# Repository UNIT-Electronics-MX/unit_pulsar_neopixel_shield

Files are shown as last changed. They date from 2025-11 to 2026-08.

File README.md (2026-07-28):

# Pulsar: Neopixel Shield

The shield matrix is designed to be compatible with the Pulsar development board format, featuring 256 RGB LEDs. This allows for independent control of each pixel to create a wide range of visual effects, from simple patterns (solid colors, bars, gradients) to complex animations (waves, scrolling text, sprites, indicators). This makes it ideal for applications in interactive displays, wearables, and creative projects.

<div align="center">
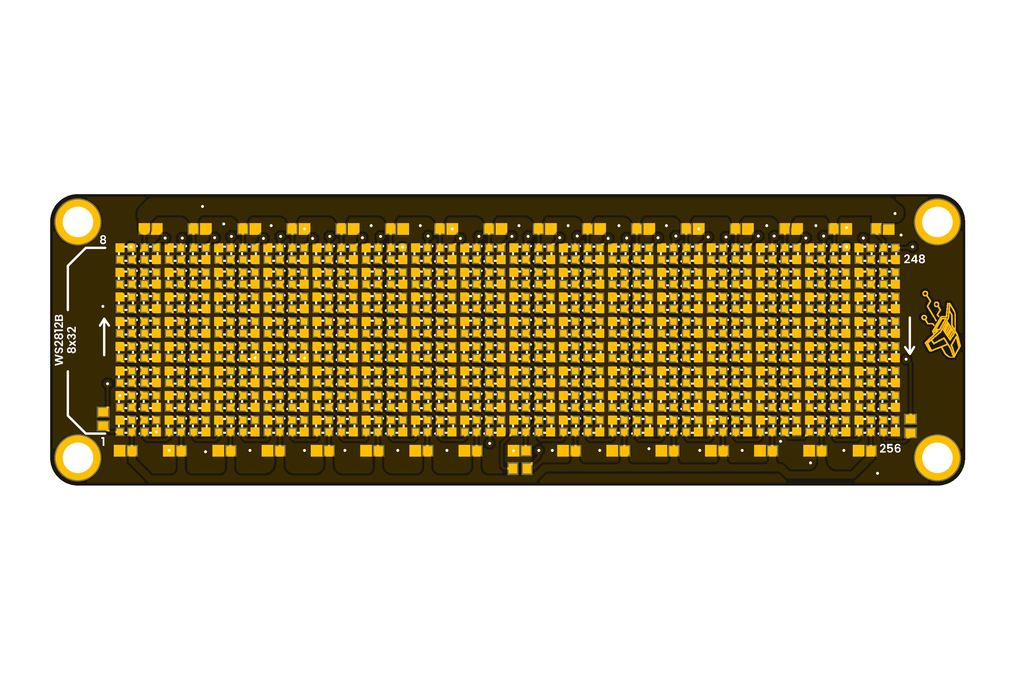
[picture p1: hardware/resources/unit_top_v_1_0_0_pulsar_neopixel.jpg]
Development Board
  
  <p><em>Development Board</em></p>
</div>

<div align="center">

### Quick Setup

[](https://wiki.uelectronics.com/wiki/unit_pulsar_neopixel_shield)
[](./hardware/unit_datasheet_v_1_0_0_ue00118_pulsar_neopixel_shield.pdf)
[](#)
[](#)

</div>

<div align="center" >

## Overview

| Feature | Description |
|---|---|
| **LED Count** | 256 RGB LEDs (WS2812B) |

</div>

## Applications

## Resources

- [Schematic Diagram](./hardware/unit_sch_v_1_0_0_pulsar_neopixel.pdf)
- [Pinout Diagram](./hardware/unit_pinout_v_1_0_0_ue00118_pulsar_neopixel_shield_en.pdf)
- [Getting Started Guide](#)

## 📝 License

All hardware and documentation in this project are licensed under the **MIT License**.  
See [`LICENSE.md`](LICENSE.md) for details.

<div align="center">
  <sub>Template created by UNIT Electronics</sub>
</div>

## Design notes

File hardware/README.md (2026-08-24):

# Hardware

<div align="center">
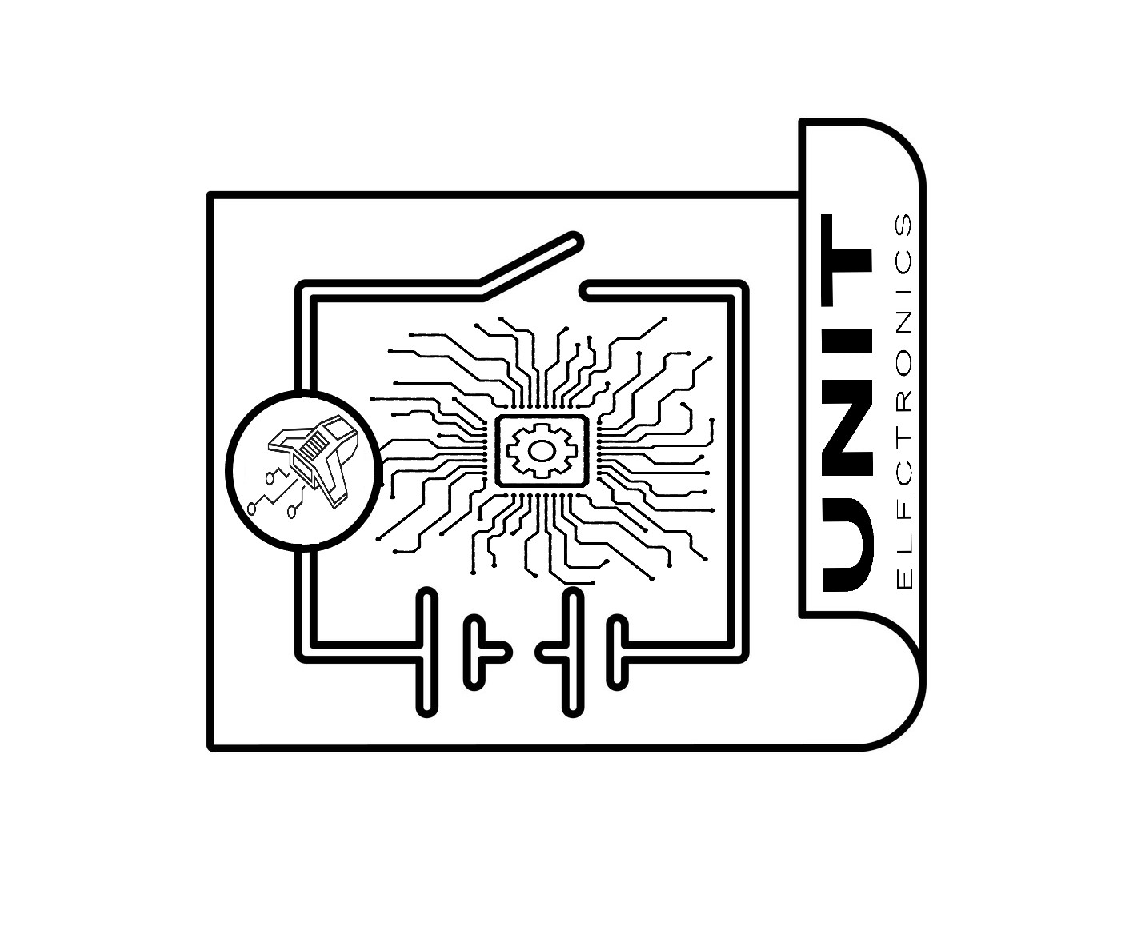
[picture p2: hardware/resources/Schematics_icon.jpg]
<a href="./unit_sch_v_1_0_0_pulsar_neopixel.pdf"><br/>Schematic</a>
</div>

## Pinout

<div align="center">
<a href="./unit_pinout_v_1_0_0_ue00118_pulsar_neopixel_shield_en.pdf">
<br/>
Pinout
</a>
</div>
    
| Pin Label | Function | Notes |
|---|---|---|
| +3V3 | Power Supply | 3.3 V power rail for the shield and external interfaces. |
| GND | Ground | Common ground reference shared by controller boards, LED matrix and expansion connectors. |
| SDA | I²C SDA (A4/D18) | Serial Data Line available through the QWIIC connector. |
| SCL | I²C SCL (A5/D19) | Serial Clock Line available through the QWIIC connector. |
| DI1 | Matrix Data Input 1 | Data input for LED Matrix 1 (LED #1 to LED #128). Available on connector J2. |
| DI2 | Matrix Data Input 2 | Data input for LED Matrix 2 (LED #129 to LED #256). Available on connector J2. |
| DO1 | Matrix Data Output 1 | Data output from Matrix 1 for cascading additional WS2812B devices. Available on connector J1. |
| DO2 | Matrix Data Output 2 | Data output from Matrix 2 for cascading additional WS2812B devices. Available on connector J1. |
| SB1 | Solder Bridge | Optional solder jumper used to electrically connect Matrix 1 and Matrix 2 for single-signal operation (DI1). |

> **SB1 Configuration:**  
> When SB1 is left open, Matrix 1 and Matrix 2 can be controlled independently through DI1 and DI2.  
> When SB1 is shorted, both matrices are electrically linked, allowing all 256 LEDs to operate as a single 8×32 addressable RGB matrix controlled from DI1.

</div>

## Dimensions

<div align="center">
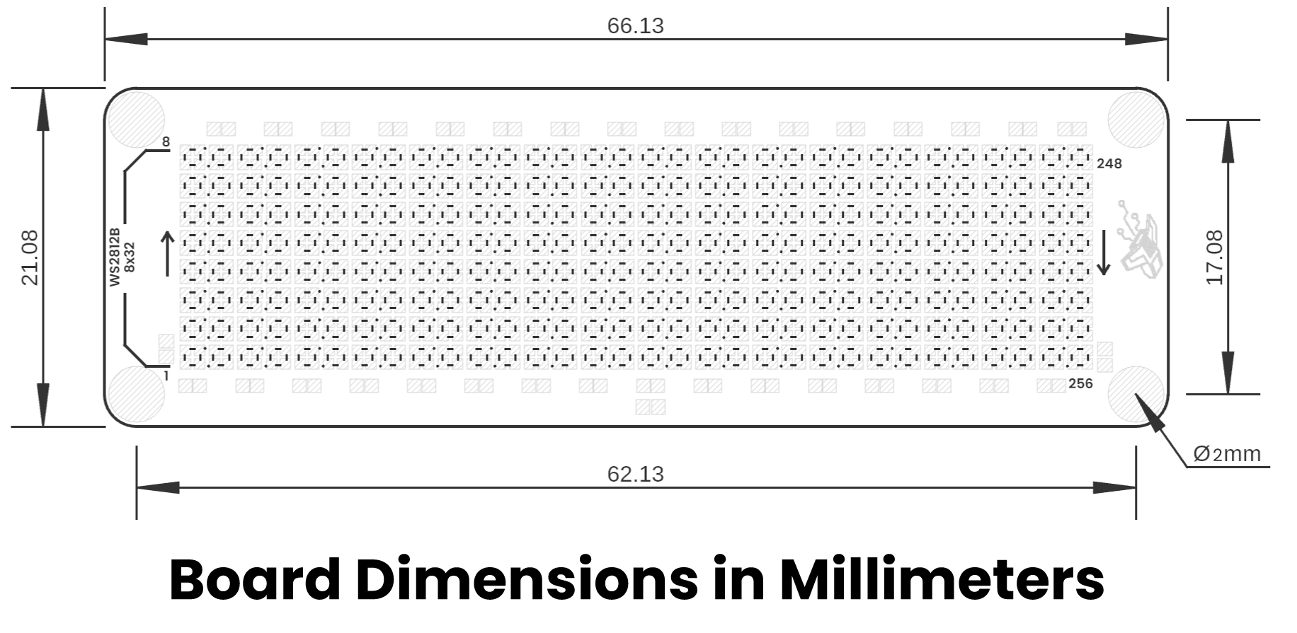
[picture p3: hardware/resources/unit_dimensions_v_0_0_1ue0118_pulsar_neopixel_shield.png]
<a href="./resources/unit_dimensions_v_0_0_1ue0118_pulsar_neopixel_shield.png"><br/> Dimensions</a>
</div>

## Topology

<div align="center">

<div align="center">
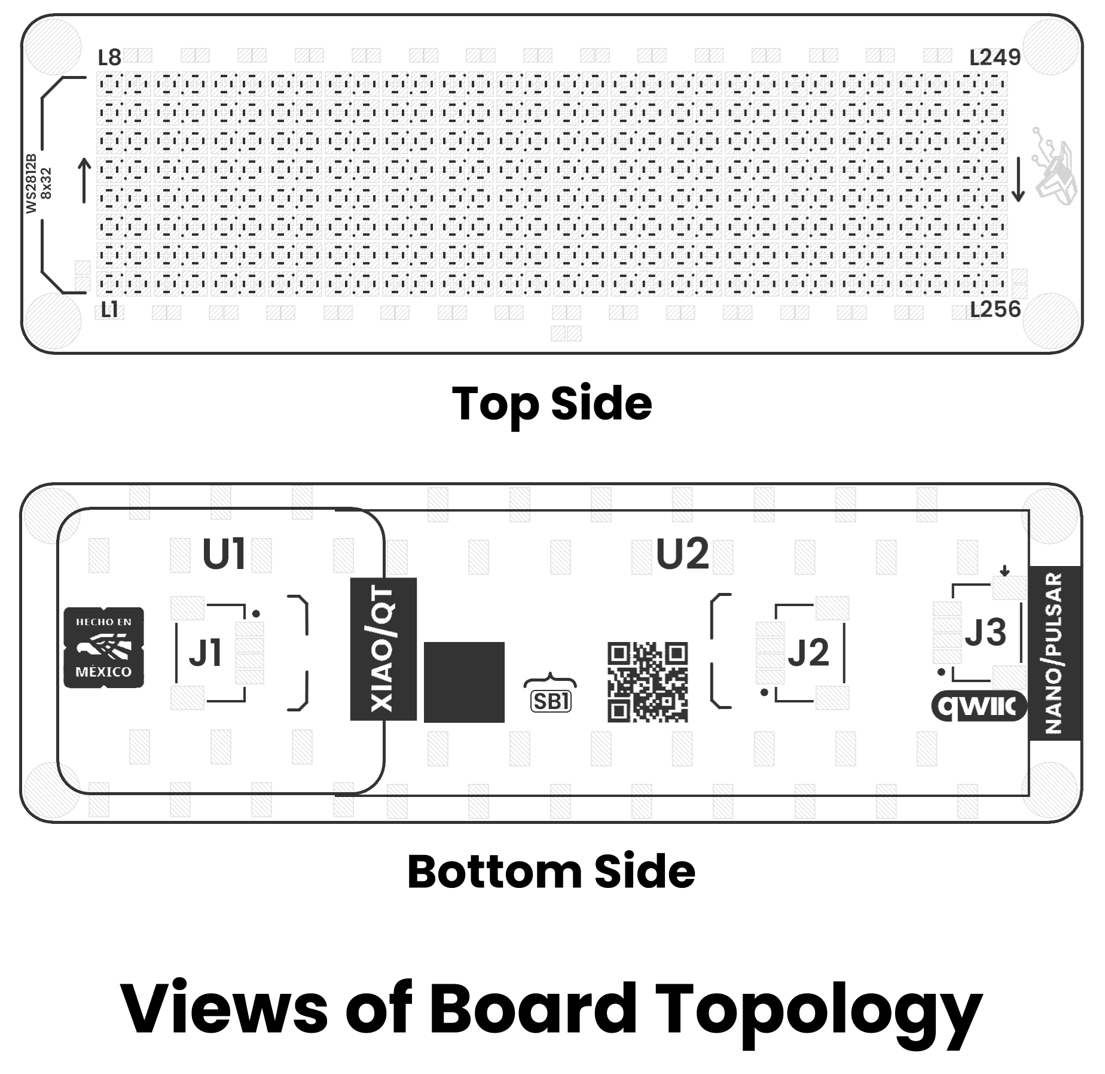
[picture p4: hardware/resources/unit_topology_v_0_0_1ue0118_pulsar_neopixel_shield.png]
<a href="./resources/unit_topology_v_0_0_1ue0118_pulsar_neopixel_shield.png"><br/> Topology</a>
<br/>
<br/>
<br/>

| Ref. | Description |
|---|---|
| L1–L256 | Addressable RGB LEDs, WS2812B-compatible, 1.0 × 1.0 mm package, SMD 1010. |
| U1 | Header connectors for inserting a Pulsar or Nano-format controller board. |
| U2 | Header connectors for inserting a XIAO/QT-format controller board. |
| J1 | WS2812B data output connector, JST 1.0 mm pitch, for external WS2812B expansion from Matrix 1 and Matrix 2. |
| J2 | WS2812B data input connector, JST 1.0 mm pitch, for Matrix 1 and Matrix 2. |
| J3 | QWIIC connector, JST 1.0 mm pitch, for I²C interface. |
| SB1 | Solder bridge/jumper pad used to join both LED matrices so they can be controlled with a single data signal. |

> **SB1 Configuration:**  
> When SB1 is left open, Matrix 1 and Matrix 2 can be controlled independently through DI1 and DI2.  
> When SB1 is shorted, the output of Matrix 1 is routed to the input of Matrix 2, allowing all 256 LEDs to operate as a single 8×32 WS2812B matrix controlled from DI1.

</div>

> **Note:** The module also includes a Qwiic/STEMMA QT connector carrying the same four signals (VCC, GND, SDA, SCL) for effortless daisy-chaining.

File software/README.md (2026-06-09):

# Software

This directory contains the software resources for the RGB LED matrix shield project.

The purpose of this folder is to organize source code, examples, tests, and future software tools related to the control and validation of the shield. The examples included here are intended to help users understand how to interact with the RGB LED matrix using different programming environments.

---

## Directory Structure

```text
software/
├── examples/
│   ├── cpp_examples/
│   └── micropython/
└── README.md
```

---

## Contents

### `examples/`

Contains example projects and test programs for the RGB LED matrix shield.

These examples are organized by programming language or development environment. The current examples are focused on C++/Arduino-based development, while MicroPython examples may be added in the future.

---

## Purpose

This software section is intended to provide:

* Basic test programs.
* Hardware validation examples.
* LED matrix control examples.
* Reference code for future development.
* Starting points for custom animations and interactive applications.

---

## Notes

The examples in this directory are mainly intended for development, debugging, and educational purposes.

Before using any example, make sure to review the pin configuration, LED count, power requirements, and library dependencies.

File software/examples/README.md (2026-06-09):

# Examples

This directory contains example projects for testing and controlling the RGB LED matrix shield.

The examples are organized by programming language or development environment. Each subdirectory contains code focused on a specific implementation or testing approach.

---

## Directory Structure

```text
examples/
├── cpp_examples/
│   ├── neo_esp/
│   ├── neo_esp_offset/
│   ├── neo_esp_test_serial/
│   └── README.md
├── micropython/
└── README.md
```

---

## Available Example Categories

### `cpp_examples/`

Contains C++ examples for controlling the RGB LED matrix using Arduino-compatible development environments.

These examples are useful for:

* Testing individual LEDs.
* Verifying LED indexing.
* Checking matrix orientation.
* Running basic animations.
* Debugging wiring and data signal issues.

---

### `micropython/`

This folder include examples for boards compatible with MicroPython, allowing the matrix shield to be controlled using Python-based scripts.

---

## Recommended Usage

Start with the examples inside `cpp_examples/` if you want to validate the hardware and confirm that the RGB LED matrix is working correctly.

A recommended first test is to use a serial-based example to check:

* Power connection.
* Data pin configuration.
* LED count.
* Matrix direction.
* Individual LED addressing.

---

## Notes

Some examples may require external libraries, such as the Adafruit NeoPixel library.

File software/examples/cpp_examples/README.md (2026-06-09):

# Interactive 8x32 RGB LED Matrix Test

This project provides an interactive serial test program for an 8x32 RGB LED matrix based on WS2812B-compatible addressable LEDs. It uses the `Adafruit_NeoPixel` library to control a total of 257 LEDs: one indicator LED and 256 matrix LEDs.

The main purpose of this code is to verify the correct operation, wiring, indexing, and physical LED arrangement of an 8x32 RGB LED matrix. Through the Serial Monitor, the user can turn on individual LEDs, complete rows, ranges of LEDs, run sequences, and perform visual verification tests.

---

## Features

* Controls an 8x32 RGB LED matrix.
* Supports 256 independently addressable matrix LEDs.
* Uses LED 0 as a status indicator.
* Allows interactive control through the Serial Monitor.
* Provides commands to test individual LEDs, rows, ranges, and full-matrix lighting.
* Includes a verification routine for checking the physical position of LEDs 9 to 16.
* Helps identify LED indexing issues and matrix wiring direction.
* Keeps the indicator LED enabled while testing the matrix.

---

## Hardware Configuration

The system is configured for the following LED layout:

| Element | Description |
| --- | --- |
| Indicator LED | LED 0 |
| Matrix LEDs | LEDs 1 to 256 |
| Matrix size | 8 columns x 32 rows |
| Data pin | Pin 8 |
| LED type | WS2812B-compatible RGB LEDs |
| Color order | GRB |
| Communication speed | 800 kHz |

The matrix is treated as a linear LED strip, where LED 0 is reserved as an indicator and the actual matrix starts at LED 1.

---

## Required Library

This project requires the following Arduino library:

```cpp
#include <Adafruit_NeoPixel.h>
```

You can install it from the Arduino IDE:

1. Open the Arduino IDE.
2. Go to **Sketch > Include Library > Manage Libraries**.
3. Search for **Adafruit NeoPixel**.
4. Install the library by Adafruit.

---

## Main Configuration

```cpp
#define PIN        8
#define NUM_LEDS   257
#define MATRIX_WIDTH  8
#define MATRIX_HEIGHT 32
```

Where:

* `PIN` defines the microcontroller pin connected to the LED matrix data input.
* `NUM_LEDS` is set to `257` because the system uses 1 indicator LED plus 256 matrix LEDs.
* `MATRIX_WIDTH` defines the number of columns in the matrix.
* `MATRIX_HEIGHT` defines the number of rows in the matrix.

---

## LED Indexing

The LED indexing is organized as follows:

* `LED 0`: status indicator.
* `LEDs 1-256`: RGB LED matrix.

The first row of the matrix uses LEDs 1 to 8.

The second row uses LEDs 9 to 16.

The third row uses LEDs 17 to 24.

This pattern continues until LED 256.

| Matrix Row | LED Range |
| --- | --- |
| Row 0 | LEDs 1-8 |
| Row 1 | LEDs 9-16 |
| Row 2 | LEDs 17-24 |
| ... | ... |
| Row 31 | LEDs 249-256 |

---

## Serial Monitor Configuration

To use the program, open the Serial Monitor with the following settings:

```text
Baud rate: 115200
Line ending: Newline
```

After uploading the code, the Serial Monitor will display an interactive menu with the available commands.

---

## Available Commands

| Command | Description | Example |
| --- | --- | --- |
| `L<num>` | Turns on an individual LED | `L1`, `L64`, `L256` |
| `F<num>` | Turns on a full row | `F0`, `F1`, `F31` |
| `C` | Clears all matrix LEDs | `C` |
| `T` | Runs a four-point reference test | `T` |
| `A` | Turns on all matrix LEDs in red | `A` |
| `S` | Runs a sequential LED test from 1 to 256 | `S` |
| `R<start>-<end>` | Turns on a range of LEDs | `R1-8`, `R20-40` |
| `V` | Verifies LEDs 9 to 16 one by one | `V` |
| `M` | Displays the command menu again | `M` |

---

## Command Descriptions

### Individual LED Test

The `L<num>` command turns on a single LED in red.

Example:

```text
L64
```

This turns on physical LED 64.

Valid range:

```text
0 to 256
```

Although LED 0 can be addressed, it is mainly used as the indicator LED.

---

### Row Test

The `F<num>` command turns on an entire matrix row.

Example:

```text
F0
```

This turns on row 0, corresponding to LEDs 1 to 8.

The row uses different colors to identify the beginning and end of the row:

* First LED: red.
* Middle LEDs: blue.
* Last LED: green.

This helps verify the physical orientation of each row.

Valid row range:

```text
0 to 31
```

---

### Clear LEDs

The `C` command turns off all matrix LEDs while keeping LED 0 enabled as a green indicator.

Example:

```text
C
```

---

### Four-Point Reference Test

The `T` command turns on four reference LEDs:

| LED | Color  | Purpose |
| --- | --- | --- |
| LED 1  | Red | Start of row 0 |
| LED 8  | Green  | End of row 0 |
| LED 9  | Blue | Start of row 1 |
| LED 16 | Yellow | End of row 1 |

This test is useful for checking the wiring direction and identifying whether the matrix follows a straight or zigzag arrangement.

Expected reference pattern:

```text
Row 0: LED 1 to LED 8
Row 1: LED 9 to LED 16
```

If the physical position does not match the expected pattern, the matrix may be wired in a zigzag layout or have a different physical LED order.

---

### Turn On All LEDs

The `A` command turns on all 256 matrix LEDs in red.

Example:

```text
A
```

This is useful for checking whether all LEDs are working correctly.

LED 0 remains enabled as a green indicator.

---

### Sequential Test

The `S` command runs a sequence from LED 1 to LED 256.

Example:

```text
S
```

Each LED turns on individually in red for 200 milliseconds.

This test helps verify:

* LED order.
* Missing LEDs.
* Incorrect wiring.
* Physical matrix direction.
* Damaged or disconnected LEDs.

To stop the sequence, send any character through the Serial Monitor.

---

### Range Test

The `R<start>-<end>` command turns on a range of LEDs in red.

Example:

```text
R1-8
```

This turns on LEDs 1 through 8.

Another example:

```text
R129-256
```

This turns on the second half of the matrix.

Valid range:

```text
1 to 256
```

---

### LED Position Verification

The `V` command verifies LEDs 9 to 16 one by one.

Example:

```text
V
```

The program turns on each LED individually and waits for the user to press Enter before continuing.

This test is useful when checking whether the second row of the matrix is physically arranged as expected.

The expected LED order for row 1 may depend on the matrix wiring. In a zigzag layout, the physical direction of every other row may be reversed.

---

## Indicator LED

LED 0 is used as a status indicator.

During setup, LED 0 is turned on with a low-intensity green color:

```cpp
strip.setPixelColor(0, strip.Color(0, 50, 0));
```

This allows the user to verify that the strip is powered and that the program is running.

The indicator LED remains on during most test operations.

---

## Brightness

The brightness is configured with:

```cpp
strip.setBrightness(64);
```

This sets the brightness to a moderate level to reduce current consumption and avoid excessive brightness during testing.

The brightness value can be adjusted from:

```text
0 to 255
```

A higher value increases brightness but also increases current consumption.

---

## Recommended Power Considerations

When turning on all 256 RGB LEDs, especially at high brightness, the matrix may require significant current. For testing purposes, the brightness is limited to 64.

For stable operation:

* Use an external power supply if required.
* Make sure the LED matrix ground and microcontroller ground are connected.
* Avoid powering a large LED matrix directly from a weak USB port.
* Use proper wire thickness for the LED power lines.
* Consider adding a capacitor across the LED power input.

---

## Troubleshooting

### Nothing turns on

Check the following:

* The data pin is connected to pin 8.
* The LED matrix is powered correctly.
* The ground of the microcontroller and the matrix are connected together.
* The correct LED type and color order are selected.
* The Adafruit NeoPixel library is installed.

---

### Colors appear incorrect

The code uses:

```cpp
NEO_GRB + NEO_KHZ800
```

If the colors do not match, the matrix may use a different color order such as RGB instead of GRB.

Try changing:

```cpp
NEO_GRB
```

to:

```cpp
NEO_RGB
```

---

### LED order does not match the expected position

If the LEDs turn on in a different physical order, the matrix may use a zigzag arrangement.

Use the following commands to diagnose the layout:

```text
T
V
S
F0
F1
```

These commands help identify the real physical order of the LEDs.

---

### Some LEDs do not turn on

Possible causes:

* Incorrect soldering.
* Damaged LED.
* Insufficient power.
* Data signal interruption.
* Incorrect LED count.
* Loose connection.

Use the sequential test:

```text
S
```

to identify the first LED where the problem appears.

---

## Code Purpose

This code is mainly intended for hardware validation and debugging of an 8x32 RGB LED matrix. It is especially useful during the development of custom LED shields, display modules, interactive panels, and embedded visual interfaces.

It can be used to verify:

* LED addressing.
* Matrix orientation.
* Data input wiring.
* Row mapping.
* Power stability.
* Individual LED functionality.

---

## Possible Improvements

Future versions of this program could include:

* XY coordinate control.
* Zigzag mapping correction.
* Text scrolling.
* Color selection through serial commands.
* Brightness adjustment through serial commands.
* Animation modes.
* Sprite rendering.
* Matrix graphics library integration.
* Support for multiple data inputs.

---

## Example Workflow

A recommended test sequence is:

```text
C
L1
L8
F0
F1
T
V
R1-16
A
S
```

This sequence allows the user to verify individual LEDs, rows, reference points, LED ranges, full matrix operation, and the complete LED order.

---

## Code

```cpp
#include <Adafruit_NeoPixel.h>

#define PIN        8
#define NUM_LEDS   257  // Total: 1 LED indicador (0) + 256 LEDs de matriz (1-256)
#define MATRIX_WIDTH  8    // 8 columnas
#define MATRIX_HEIGHT 32   // 32 filas

Adafruit_NeoPixel strip(NUM_LEDS, PIN, NEO_GRB + NEO_KHZ800);

void setup() {
  Serial.begin(115200);
  
  strip.begin();
  strip.setBrightness(64);
  strip.clear();
  
  // LED 0 como indicador
  
  strip.setPixelColor(0, strip.Color(0, 50, 0));
  strip.show();
  
  Serial.println("\n\n=== PRUEBA INTERACTIVA LED MATRIZ 8x32 ===");
  Serial.println("LED 0: Indicador (verde tenue)");
  Serial.println("Matriz: LEDs 1-256 (8 columnas x 32 filas)\n");
  
  printMenu();
}

void printMenu() {
  Serial.println("\n--- MENU DE COMANDOS ---");
  Serial.println("L<num>        - Encender LED individual (ej: L1, L64, L256)");
  Serial.println("F<num>        - Encender fila completa (ej: F0, F1, F31)");
  Serial.println("C             - Limpiar todos los LEDs");
  Serial.println("T             - Test 4 esquinas (LEDs 1,8,9,16)");
  Serial.println("A             - Encender TODOS los LEDs en ROJO");
  Serial.println("S             - Secuencia 1-256 uno por uno");
  Serial.println("R<inicio>-<fin> - Rango de LEDs (ej: R1-8)");
  Serial.println("V             - Verificar LEDs 9-16 uno por uno");
  Serial.println("M             - Mostrar este menu");
  Serial.println("\nColores: ROJO por defecto");
  Serial.println("----------------------------------------\n");
}

void encenderLED(int ledNum) {
  if (ledNum < 0 || ledNum > 256) {
    Serial.println("ERROR: LED debe estar entre 0 y 256");
    return;
  }
  
  strip.clear();
  // Mantener LED 0 encendido
  strip.setPixelColor(0, strip.Color(0, 50, 0));
  
  Serial.print("DEBUG: Encendiendo LED fisico ");
  Serial.println(ledNum);
  
  // Encender el LED solicitado en ROJO
  strip.setPixelColor(ledNum, strip.Color(255, 0, 0));
  strip.show();
  
  Serial.print("LED ");
  Serial.print(ledNum);
  Serial.println(" encendido (ROJO)");
}

void encenderFila(int fila) {
  if (fila < 0 || fila >= MATRIX_HEIGHT) {
    Serial.print("ERROR: Fila debe estar entre 0 y ");
    Serial.println(MATRIX_HEIGHT - 1);
    return;
  }
  
  strip.clear();
  // Mantener LED 0 encendido
  strip.setPixelColor(0, strip.Color(0, 50, 0));
  
  // Calcular LEDs de la fila (sin offset porque son LEDs físicos directos)
  int startLED = (fila * MATRIX_WIDTH) + 1; // +1 porque LED 0 es indicador
  
  Serial.print("Fila ");
  Serial.print(fila);
  Serial.print(" - LEDs fisicos: ");
  Serial.print(startLED);
  Serial.print(" a ");
  Serial.println(startLED + MATRIX_WIDTH - 1);
  
  // Encender los 8 LEDs de la fila con colores alternados
  for (int i = 0; i < MATRIX_WIDTH; i++) {
    int ledNum = startLED + i;
    // Alternar colores para identificar cada LED
    if (i == 0) {
      strip.setPixelColor(ledNum, strip.Color(255, 0, 0)); // ROJO - primero
      Serial.print("  LED ");
      Serial.print(ledNum);
      Serial.println(": ROJO (primero)");
    } else if (i == 7) {  // Último LED (columna 7)
      strip.setPixelColor(ledNum, strip.Color(0, 255, 0)); // VERDE - último
      Serial.print("  LED ");
      Serial.print(ledNum);
      Serial.println(": VERDE (ultimo)");
    } else {
      strip.setPixelColor(ledNum, strip.Color(0, 0, 255)); // AZUL - intermedios
    }
  }
  
  strip.show();
}

void limpiarTodo() {
  strip.clear();
  strip.setPixelColor(0, strip.Color(0, 50, 0));
  strip.show();
  Serial.println("Todos los LEDs apagados (excepto indicador)");
}

void encenderTodos() {
  strip.clear();
  strip.setPixelColor(0, strip.Color(0, 50, 0)); // Mantener indicador
  
  // Encender todos los LEDs de la matriz (1-256) en ROJO
  for (int i = 1; i <= 256; i++) {
    strip.setPixelColor(i, strip.Color(255, 0, 0));
  }
  
  strip.show();
  Serial.println("\n=== TODOS LOS LEDs ENCENDIDOS EN ROJO ===");
  Serial.println("LEDs 1-256 encendidos");
  Serial.println("Verifica que todos los LEDs fisicos esten encendidos");
}

void testEsquinas() {
  strip.clear();
  strip.setPixelColor(0, strip.Color(0, 50, 0));
  
  // Fila 0 - primera y última columna
  strip.setPixelColor(1, strip.Color(255, 0, 0));    // LED 1 - ROJO (esquina superior izquierda)
  strip.setPixelColor(8, strip.Color(0, 255, 0));    // LED 8 - VERDE (esquina superior derecha)
  
  // Fila 1 - primera y última columna  
  strip.setPixelColor(9, strip.Color(0, 0, 255));    // LED 9 - AZUL (fila 1, inicio)
  strip.setPixelColor(16, strip.Color(255, 255, 0)); // LED 16 - AMARILLO (fila 1, final)
  
  strip.show();
  
  Serial.println("\n=== TEST 4 PUNTOS CLAVE ===");
  Serial.println("LED 1:  ROJO     (Fila 0, columna 0 - inicio)");
  Serial.println("LED 8:  VERDE    (Fila 0, columna 7 - final)");
  Serial.println("LED 9:  AZUL     (Fila 1, columna 0 - inicio)");
  Serial.println("LED 16: AMARILLO (Fila 1, columna 7 - final)");
  Serial.println("\nPatron zigzag esperado:");
  Serial.println("Fila 0: ROJO -> -> -> VERDE (izq a der, LEDs 1-8)");
  Serial.println("Fila 1: AMARILLO <- <- <- AZUL (der a izq, LEDs 9-16)");
}

void secuencia() {
  Serial.println("\nIniciando secuencia 1-256...");
  Serial.println("Presiona cualquier tecla para detener\n");
  
  for (int i = 1; i <= 256; i++) {
    if (Serial.available() > 0) {
      Serial.read(); // Leer y descartar
      Serial.println("\nSecuencia detenida");
      break;
    }
    
    strip.clear();
    strip.setPixelColor(0, strip.Color(0, 50, 0));
    strip.setPixelColor(i, strip.Color(255, 0, 0));
    strip.show();
    
    Serial.print("LED ");
    Serial.println(i);
    delay(200);
  }
  
  Serial.println("Secuencia completada");
}

void encenderRango(int inicio, int fin) {
  if (inicio < 1 || fin > 256 || inicio > fin) {
    Serial.println("ERROR: Rango invalido (debe ser 1-256)");
    return;
  }
  
  strip.clear();
  strip.setPixelColor(0, strip.Color(0, 50, 0));
  
  for (int i = inicio; i <= fin; i++) {
    strip.setPixelColor(i, strip.Color(255, 0, 0));
  }
  
  strip.show();
  
  Serial.print("LEDs ");
  Serial.print(inicio);
  Serial.print(" a ");
  Serial.print(fin);
  Serial.println(" encendidos (ROJO)");
}

void verificarProblema() {
  Serial.println("\n=== VERIFICACION LEDs 9-16 (Fila 1) ===");
  Serial.println("Encendiendo cada LED individualmente...");
  Serial.println("Observa DONDE se enciende fisicamente cada LED:\n");
  
  for (int i = 9; i <= 16; i++) {
    strip.clear();
    strip.setPixelColor(0, strip.Color(0, 50, 0));
    strip.setPixelColor(i, strip.Color(255, 0, 0));
    strip.show();
    
    Serial.print(">>> LED FISICO ");
    Serial.print(i);
    Serial.println(" ENCENDIDO <<<");
    Serial.println("Anota la posicion fisica en tu matriz (fila/columna)");
    Serial.println("Presiona Enter para continuar...\n");
    
    // Esperar input del usuario
    while (Serial.available() == 0) {
      delay(10);
    }
    // Limpiar buffer
    while (Serial.available() > 0) {
      Serial.read();
    }
  }
  
  Serial.println("\n=== Verificacion completada ===");
  Serial.println("Ahora compara las posiciones fisicas con lo esperado:");
  Serial.println("Fila 1 deberia ser: LEDs 9-16 (en zigzag: 16,15,14,13,12,11,10,9)");
  limpiarTodo();
}

void procesarComando(String comando) {
  comando.trim();
  comando.toUpperCase();
  
  Serial.print("DEBUG: Comando recibido: [");
  Serial.print(comando);
  Serial.print("], Longitud: ");
  Serial.println(comando.length());
  
  if (comando.length() == 0) {
    Serial.println("DEBUG: Comando vacio");
    return;
  }
  
  char cmd = comando.charAt(0);
  
  Serial.print("DEBUG: Primer caracter: [");
  Serial.print(cmd);
  Serial.println("]");
  
  switch(cmd) {
    case 'L': {
      // Encender LED individual: L64
      int ledNum = comando.substring(1).toInt();
      Serial.print("DEBUG: Numero parseado del substring: ");
      Serial.println(ledNum);
      encenderLED(ledNum);
      break;
    }
    
    case 'F': {
      // Encender fila: F0, F1, etc
      int fila = comando.substring(1).toInt();
      encenderFila(fila);
      break;
    }
    
    case 'C': {
      // Limpiar todo
      limpiarTodo();
      break;
    }
    
    case 'T': {
      // Test 4 esquinas
      testEsquinas();
      break;
    }
    
    case 'A': {
      // Encender TODOS los LEDs
      encenderTodos();
      break;
    }
    
    case 'S': {
      // Secuencia completa
      secuencia();
      break;
    }
    
    case 'R': {
      // Rango: R1-16
      int guionPos = comando.indexOf('-');
      if (guionPos > 0) {
        int inicio = comando.substring(1, guionPos).toInt();
        int fin = comando.substring(guionPos + 1).toInt();
        encenderRango(inicio, fin);
      } else {
        Serial.println("ERROR: Formato incorrecto. Usar R<inicio>-<fin>");
      }
      break;
    }
    
    case 'V': {
      // Verificar problema LEDs 9-17
      verificarProblema();
      break;
    }
    
    case 'M': {
      // Mostrar menu
      printMenu();
      break;
    }
    
    default:
      Serial.println("Comando no reconocido. Escribe M para ver el menu");
      break;
  }
}

void loop() {
  if (Serial.available() > 0) {
    String comando = Serial.readStringUntil('\n');
    procesarComando(comando);
  }
}
```

## License

This project can be used, modified, and adapted for educational, prototyping, and hardware testing purposes.

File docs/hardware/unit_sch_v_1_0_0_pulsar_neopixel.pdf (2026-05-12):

WS2812B | WS2812B | WS2812B | WS2812B | WS2812B | WS2812B | WS2812B | WS2812B VCC
VCC | VCC | VCC | VCC | VCC | VCC | VCC
GND | GND | GND | GND | GND | GND | GND | GND
WS2812B | WS2812B | WS2812B | WS2812B | WS2812B | WS2812B | WS2812B | WS2812B VCC
VCC | VCC | VCC | VCC | VCC | VCC | VCC
GND | GND | GND | GND | GND | GND | GND | GND
WS2812B | WS2812B | WS2812B | WS2812B | WS2812B | WS2812B | WS2812B | WS2812B VCC
VCC | VCC | VCC | VCC | VCC | VCC | VCC
GND | GND | GND | GND | GND | GND | GND | GND
WS2812B | WS2812B | WS2812B | WS2812B | WS2812B | WS2812B | WS2812B | WS2812B VCC
VCC | VCC | VCC | VCC | VCC | VCC | VCC
GND | GND | GND | GND | GND | GND | GND | GND
WS2812B | WS2812B | WS2812B | WS2812B | WS2812B | WS2812B | WS2812B | WS2812B VCC
VCC | VCC | VCC | VCC | VCC | VCC | VCC
GND | GND | GND | GND | GND | GND | GND | GND
WS2812B | WS2812B | WS2812B | WS2812B | WS2812B | WS2812B | WS2812B | WS2812B VCC
VCC | VCC | VCC | VCC | VCC | VCC | VCC
GND | GND | GND | GND | GND | GND | GND | GND
WS2812B | WS2812B | WS2812B | WS2812B | WS2812B | WS2812B | WS2812B | WS2812B VCC
VCC | VCC | VCC | VCC | VCC | VCC | VCC
GND | GND | GND | GND | GND | GND | GND | GND
WS2812B | WS2812B | WS2812B | WS2812B | WS2812B | WS2812B | WS2812B | WS2812B VCC
VCC | VCC | VCC | VCC | VCC | VCC | VCC
GND | GND | GND | GND | GND | GND | GND | GND

1uF

### VCC

### GND

1uF

### VCC

### GND

1uF

### VCC

### GND

1uF

### VCC

### GND

1uF

### VCC

### GND

1uF

### VCC

GND | 1uF VCC | GND | 1uF VCC | GND ²⁰⁰ | LED1 DO | P$1 GND | P$3 DI P$4 | VDD P$2
LED2 DO | P$1 GND | P$3 DI P$4 | VDD P$2
LED3 DO | P$1 GND | P$3 DI P$4 | VDD P$2
LED4 DO | P$1 GND | P$3 DI P$4 | VDD P$2
LED5 DO | P$1 GND | P$3 DI P$4 | VDD P$2
LED6 DO | P$1 GND | P$3 DI P$4 | VDD P$2
LED7 DO | P$1 GND | P$3 DI P$4 | VDD P$2
LED8 DO | P$1 GND | P$3 DI P$4 | VDD P$2
LED9 DO | P$1 GND | P$3 DI P$4 | VDD P$2
LED10 DO | P$1 GND | P$3 DI P$4 | VDD P$2
LED11 DO | P$1 GND | P$3 DI P$4 | VDD P$2
LED12 DO | P$1 GND | P$3 DI P$4 | VDD P$2
LED13 DO | P$1 GND | P$3 DI P$4 | VDD P$2
LED14 DO | P$1 GND | P$3 DI P$4 | VDD P$2
LED15 DO | P$1 GND | P$3 DI P$4 | VDD P$2
LED16 DO | P$1 GND | P$3 DI P$4 | VDD P$2
LED17 DO | P$1 GND | P$3 DI P$4 | VDD P$2
LED18 DO | P$1 GND | P$3 DI P$4 | VDD P$2
LED19 DO | P$1 GND | P$3 DI P$4 | VDD P$2
LED20 DO | P$1 GND | P$3 DI P$4 | VDD P$2
LED21 DO | P$1 GND | P$3 DI P$4 | VDD P$2
LED22 DO | P$1 GND | P$3 DI P$4 | VDD P$2
LED23 DO | P$1 GND | P$3 DI P$4 | VDD P$2
LED24 DO | P$1 GND | P$3 DI P$4 | VDD P$2
LED25 DO | P$1 GND | P$3 DI P$4 | VDD P$2
LED26 DO | P$1 GND | P$3 DI P$4 | VDD P$2
LED27 DO | P$1 GND | P$3 DI P$4 | VDD P$2
LED28 DO | P$1 GND | P$3 DI P$4 | VDD P$2
LED29 DO | P$1 GND | P$3 DI P$4 | VDD P$2
LED30 DO | P$1 GND | P$3 DI P$4 | VDD P$2
LED31 DO | P$1 GND | P$3 DI P$4 | VDD P$2
LED32 DO | P$1 GND | P$3 DI P$4 | VDD P$2
LED33 DO | P$1 GND | P$3 DI P$4 | VDD P$2
LED34 DO | P$1 GND | P$3 DI P$4 | VDD P$2
LED35 DO | P$1 GND | P$3 DI P$4 | VDD P$2
LED36 DO | P$1 GND | P$3 DI P$4 | VDD P$2
LED37 DO | P$1 GND | P$3 DI P$4 | VDD P$2
LED38 DO | P$1 GND | P$3 DI P$4 | VDD P$2
LED39 DO | P$1 GND | P$3 DI P$4 | VDD P$2
LED40 DO | P$1 GND | P$3 DI P$4 | VDD P$2
LED41 DO | P$1 GND | P$3 DI P$4 | VDD P$2
LED42 DO | P$1 GND | P$3 DI P$4 | VDD P$2
LED43 DO | P$1 GND | P$3 DI P$4 | VDD P$2
LED44 DO | P$1 GND | P$3 DI P$4 | VDD P$2
LED45 DO | P$1 GND | P$3 DI P$4 | VDD P$2
LED46 DO | P$1 GND | P$3 DI P$4 | VDD P$2
LED47 DO | P$1 GND | P$3 DI P$4 | VDD P$2
LED48 DO | P$1 GND | P$3 DI P$4 | VDD P$2
LED49 DO | P$1 GND | P$3 DI P$4 | VDD P$2
LED50 DO | P$1 GND | P$3 DI P$4 | VDD P$2
LED51 DO | P$1 GND | P$3 DI P$4 | VDD P$2
LED52 DO | P$1 GND | P$3 DI P$4 | VDD P$2
LED53 DO | P$1 GND | P$3 DI P$4 | VDD P$2
LED54 DO | P$1 GND | P$3 DI P$4 | VDD P$2
LED55 DO | P$1 GND | P$3 DI P$4 | VDD P$2
LED56 DO | P$1 GND | P$3 DI P$4 | VDD P$2
LED57 DO | P$1 GND | P$3 DI P$4 | VDD P$2
LED58 DO | P$1 GND | P$3 DI P$4 | VDD P$2
LED59 DO | P$1 GND | P$3 DI P$4 | VDD P$2
LED60 DO | P$1 GND | P$3 DI P$4 | VDD P$2
LED61 DO | P$1 GND | P$3 DI P$4 | VDD P$2
LED62 DO | P$1 GND | P$3 DI P$4 | VDD P$2
LED63 DO | P$1 GND | P$3 DI P$4 | VDD P$2
LED64 DO | P$1 GND | P$3 DI P$4 | VDD P$2

C9

C10

C11

C12

C13

C14 | C¹⁵ | C¹⁶ R¹ DI1/5.2B | DO¹/2.1A
UE0112 | 1 Matrix 1

A

B | B
C | C
D | D

E

1 | 2 | 3 | 4 | 5 | 6 | 7 | 8

A

E

07/10/2025 05:48 p. m. | 1 | 5 Title: UE0118-Neopixel Shield v9
SKU: Last date time: | REV: SHEET: | of File: | Sheet description: | Author: Alberto Villanueva THE INFORMATION CONTAINED IN THIS DRAWING IS THE SOLE PROPERTY OF UNIT ELECTRONICS. ANY REPRODUCTION IN PART OR WHOLE IS

STRICTLY PROHIBITED WITHOUT WRITTEN PERMISSION. PROPRIETARY

WS2812B | WS2812B | WS2812B | WS2812B | WS2812B | WS2812B | WS2812B | WS2812B VCC
VCC | VCC | VCC | VCC | VCC | VCC | VCC
WS2812B | WS2812B | WS2812B | WS2812B | WS2812B | WS2812B | WS2812B | WS2812B VCC
VCC | VCC | VCC | VCC | VCC | VCC | VCC
GND | GND | GND | GND | GND | GND | GND | GND
WS2812B | WS2812B | WS2812B | WS2812B | WS2812B | WS2812B | WS2812B | WS2812B VCC
VCC | VCC | VCC | VCC | VCC | VCC | VCC
GND | GND | GND | GND | GND | GND | GND | GND
WS2812B | WS2812B | WS2812B | WS2812B | WS2812B | WS2812B | WS2812B | WS2812B VCC
VCC | VCC | VCC | VCC | VCC | VCC | VCC
GND | GND | GND | GND | GND | GND | GND | GND
WS2812B | WS2812B | WS2812B | WS2812B | WS2812B | WS2812B | WS2812B | WS2812B VCC
VCC | VCC | VCC | VCC | VCC | VCC | VCC
GND | GND | GND | GND | GND | GND | GND | GND
WS2812B | WS2812B | WS2812B | WS2812B | WS2812B | WS2812B | WS2812B | WS2812B VCC
VCC | VCC | VCC | VCC | VCC | VCC | VCC
GND | GND | GND | GND | GND | GND | GND | GND
WS2812B | WS2812B | WS2812B | WS2812B | WS2812B | WS2812B | WS2812B | WS2812B VCC
VCC | VCC | VCC | VCC | VCC | VCC | VCC
GND | GND | GND | GND | GND | GND | GND | GND
WS2812B | WS2812B | WS2812B | WS2812B | WS2812B | WS2812B | WS2812B | WS2812B VCC
VCC | VCC | VCC | VCC | VCC | VCC | VCC
GND | GND | GND | GND | GND | GND | GND | GND

1uF

### VCC

### GND

1uF

### VCC

### GND

1uF

### VCC

### GND

1uF

### VCC

### GND

1uF

### VCC

### GND

1uF

### VCC

GND | 1uF VCC | GND | 1uF VCC | GND
LED65 DO | P$1 GND | P$3 DI P$4 | VDD P$2
LED66 DO | P$1 GND | P$3 DI P$4 | VDD P$2
LED67 DO | P$1 GND | P$3 DI P$4 | VDD P$2
LED68 DO | P$1 GND | P$3 DI P$4 | VDD P$2
LED69 DO | P$1 GND | P$3 DI P$4 | VDD P$2
LED70 DO | P$1 GND | P$3 DI P$4 | VDD P$2
LED71 DO | P$1 GND | P$3 DI P$4 | VDD P$2
LED72 DO | P$1 GND | P$3 DI P$4 | VDD P$2
LED73 DO | P$1 GND | P$3 DI P$4 | VDD P$2
LED74 DO | P$1 GND | P$3 DI P$4 | VDD P$2
LED75 DO | P$1 GND | P$3 DI P$4 | VDD P$2
LED76 DO | P$1 GND | P$3 DI P$4 | VDD P$2
LED77 DO | P$1 GND | P$3 DI P$4 | VDD P$2
LED78 DO | P$1 GND | P$3 DI P$4 | VDD P$2
LED79 DO | P$1 GND | P$3 DI P$4 | VDD P$2
LED80 DO | P$1 GND | P$3 DI P$4 | VDD P$2
LED81 DO | P$1 GND | P$3 DI P$4 | VDD P$2
LED82 DO | P$1 GND | P$3 DI P$4 | VDD P$2
LED83 DO | P$1 GND | P$3 DI P$4 | VDD P$2
LED84 DO | P$1 GND | P$3 DI P$4 | VDD P$2
LED85 DO | P$1 GND | P$3 DI P$4 | VDD P$2
LED86 DO | P$1 GND | P$3 DI P$4 | VDD P$2
LED87 DO | P$1 GND | P$3 DI P$4 | VDD P$2
LED88 DO | P$1 GND | P$3 DI P$4 | VDD P$2
LED89 DO | P$1 GND | P$3 DI P$4 | VDD P$2
LED90 DO | P$1 GND | P$3 DI P$4 | VDD P$2
LED91 DO | P$1 GND | P$3 DI P$4 | VDD P$2
LED92 DO | P$1 GND | P$3 DI P$4 | VDD P$2
LED93 DO | P$1 GND | P$3 DI P$4 | VDD P$2
LED94 DO | P$1 GND | P$3 DI P$4 | VDD P$2
LED95 DO | P$1 GND | P$3 DI P$4 | VDD P$2
LED96 DO | P$1 GND | P$3 DI P$4 | VDD P$2
LED97 DO | P$1 GND | P$3 DI P$4 | VDD P$2
LED98 DO | P$1 GND | P$3 DI P$4 | VDD P$2
LED99 DO | P$1 GND | P$3 DI P$4 | VDD P$2
LED100 DO | P$1 GND | P$3 DI P$4 | VDD P$2
LED101 DO | P$1 GND | P$3 DI P$4 | VDD P$2
LED102 DO | P$1 GND | P$3 DI P$4 | VDD P$2
LED103 DO | P$1 GND | P$3 DI P$4 | VDD P$2
LED104 DO | P$1 GND | P$3 DI P$4 | VDD P$2
LED105 DO | P$1 GND | P$3 DI P$4 | VDD P$2
LED106 DO | P$1 GND | P$3 DI P$4 | VDD P$2
LED107 DO | P$1 GND | P$3 DI P$4 | VDD P$2
LED108 DO | P$1 GND | P$3 DI P$4 | VDD P$2
LED109 DO | P$1 GND | P$3 DI P$4 | VDD P$2
LED110 DO | P$1 GND | P$3 DI P$4 | VDD P$2
LED111 DO | P$1 GND | P$3 DI P$4 | VDD P$2
LED112 DO | P$1 GND | P$3 DI P$4 | VDD P$2
LED113 DO | P$1 GND | P$3 DI P$4 | VDD P$2
LED114 DO | P$1 GND | P$3 DI P$4 | VDD P$2
LED115 DO | P$1 GND | P$3 DI P$4 | VDD P$2
LED116 DO | P$1 GND | P$3 DI P$4 | VDD P$2
LED117 DO | P$1 GND | P$3 DI P$4 | VDD P$2
LED118 DO | P$1 GND | P$3 DI P$4 | VDD P$2
LED119 DO | P$1 GND | P$3 DI P$4 | VDD P$2
LED120 DO | P$1 GND | P$3 DI P$4 | VDD P$2
LED121 DO | P$1 GND | P$3 DI P$4 | VDD P$2
LED122 DO | P$1 GND | P$3 DI P$4 | VDD P$2
LED123 DO | P$1 GND | P$3 DI P$4 | VDD P$2
LED124 DO | P$1 GND | P$3 DI P$4 | VDD P$2
LED125 DO | P$1 GND | P$3 DI P$4 | VDD P$2
LED126 DO | P$1 GND | P$3 DI P$4 | VDD P$2
LED127 DO | P$1 GND | P$3 DI P$4 | VDD P$2
LED128 DO | P$1 GND | P$3 DI P$4 | VDD P$2

C1

C2

C3

C4

C5

C6 | C⁷ | C⁸ DO¹/1.8E | DO²/5.3B
UE0112 | 1 Matrix 2

A

B | B
C | C
D | D

E

A

E

07/10/2025 05:48 p. m. | 2 | 5 Title: UE0118-Neopixel Shield v9
SKU: Last date time: | REV: SHEET: | of File: | Sheet description: | Author: Alberto Villanueva THE INFORMATION CONTAINED IN THIS DRAWING IS THE SOLE PROPERTY OF UNIT ELECTRONICS. ANY REPRODUCTION IN PART OR WHOLE IS

WS2812B | WS2812B | WS2812B | WS2812B | WS2812B | WS2812B | WS2812B | WS2812B VCC
VCC | VCC | VCC | VCC | VCC | VCC | VCC
WS2812B | WS2812B | WS2812B | WS2812B | WS2812B | WS2812B | WS2812B | WS2812B VCC
VCC | VCC | VCC | VCC | VCC | VCC | VCC
GND | GND | GND | GND | GND | GND | GND | GND
WS2812B | WS2812B | WS2812B | WS2812B | WS2812B | WS2812B | WS2812B | WS2812B VCC
VCC | VCC | VCC | VCC | VCC | VCC | VCC
GND | GND | GND | GND | GND | GND | GND | GND
WS2812B | WS2812B | WS2812B | WS2812B | WS2812B | WS2812B | WS2812B | WS2812B VCC
VCC | VCC | VCC | VCC | VCC | VCC | VCC
GND | GND | GND | GND | GND | GND | GND | GND
WS2812B | WS2812B | WS2812B | WS2812B | WS2812B | WS2812B | WS2812B | WS2812B VCC
VCC | VCC | VCC | VCC | VCC | VCC | VCC
GND | GND | GND | GND | GND | GND | GND | GND
WS2812B | WS2812B | WS2812B | WS2812B | WS2812B | WS2812B | WS2812B | WS2812B VCC
VCC | VCC | VCC | VCC | VCC | VCC | VCC
GND | GND | GND | GND | GND | GND | GND | GND
WS2812B | WS2812B | WS2812B | WS2812B | WS2812B | WS2812B | WS2812B | WS2812B VCC
VCC | VCC | VCC | VCC | VCC | VCC | VCC
GND | GND | GND | GND | GND | GND | GND | GND
WS2812B | WS2812B | WS2812B | WS2812B | WS2812B | WS2812B | WS2812B | WS2812B VCC
VCC | VCC | VCC | VCC | VCC | VCC | VCC
GND | GND | GND | GND | GND | GND | GND | GND

1uF

### VCC

### GND

1uF

### VCC

### GND

1uF

### VCC

### GND

1uF

### VCC

### GND

1uF

### VCC

### GND

1uF

### VCC

GND | 1uF VCC | GND | 1uF VCC | GND ²⁰⁰ | LED129 DO | P$1 GND | P$3 DI P$4 | VDD P$2
LED130 DO | P$1 GND | P$3 DI P$4 | VDD P$2
LED131 DO | P$1 GND | P$3 DI P$4 | VDD P$2
LED132 DO | P$1 GND | P$3 DI P$4 | VDD P$2
LED133 DO | P$1 GND | P$3 DI P$4 | VDD P$2
LED134 DO | P$1 GND | P$3 DI P$4 | VDD P$2
LED135 DO | P$1 GND | P$3 DI P$4 | VDD P$2
LED136 DO | P$1 GND | P$3 DI P$4 | VDD P$2
LED137 DO | P$1 GND | P$3 DI P$4 | VDD P$2
LED138 DO | P$1 GND | P$3 DI P$4 | VDD P$2
LED139 DO | P$1 GND | P$3 DI P$4 | VDD P$2
LED140 DO | P$1 GND | P$3 DI P$4 | VDD P$2
LED141 DO | P$1 GND | P$3 DI P$4 | VDD P$2
LED142 DO | P$1 GND | P$3 DI P$4 | VDD P$2
LED143 DO | P$1 GND | P$3 DI P$4 | VDD P$2
LED144 DO | P$1 GND | P$3 DI P$4 | VDD P$2
LED145 DO | P$1 GND | P$3 DI P$4 | VDD P$2
LED146 DO | P$1 GND | P$3 DI P$4 | VDD P$2
LED147 DO | P$1 GND | P$3 DI P$4 | VDD P$2
LED148 DO | P$1 GND | P$3 DI P$4 | VDD P$2
LED149 DO | P$1 GND | P$3 DI P$4 | VDD P$2
LED150 DO | P$1 GND | P$3 DI P$4 | VDD P$2
LED151 DO | P$1 GND | P$3 DI P$4 | VDD P$2
LED152 DO | P$1 GND | P$3 DI P$4 | VDD P$2
LED153 DO | P$1 GND | P$3 DI P$4 | VDD P$2
LED154 DO | P$1 GND | P$3 DI P$4 | VDD P$2
LED155 DO | P$1 GND | P$3 DI P$4 | VDD P$2
LED156 DO | P$1 GND | P$3 DI P$4 | VDD P$2
LED157 DO | P$1 GND | P$3 DI P$4 | VDD P$2
LED158 DO | P$1 GND | P$3 DI P$4 | VDD P$2
LED159 DO | P$1 GND | P$3 DI P$4 | VDD P$2
LED160 DO | P$1 GND | P$3 DI P$4 | VDD P$2
LED161 DO | P$1 GND | P$3 DI P$4 | VDD P$2
LED162 DO | P$1 GND | P$3 DI P$4 | VDD P$2
LED163 DO | P$1 GND | P$3 DI P$4 | VDD P$2
LED164 DO | P$1 GND | P$3 DI P$4 | VDD P$2
LED165 DO | P$1 GND | P$3 DI P$4 | VDD P$2
LED166 DO | P$1 GND | P$3 DI P$4 | VDD P$2
LED167 DO | P$1 GND | P$3 DI P$4 | VDD P$2
LED168 DO | P$1 GND | P$3 DI P$4 | VDD P$2
LED169 DO | P$1 GND | P$3 DI P$4 | VDD P$2
LED170 DO | P$1 GND | P$3 DI P$4 | VDD P$2
LED171 DO | P$1 GND | P$3 DI P$4 | VDD P$2
LED172 DO | P$1 GND | P$3 DI P$4 | VDD P$2
LED173 DO | P$1 GND | P$3 DI P$4 | VDD P$2
LED174 DO | P$1 GND | P$3 DI P$4 | VDD P$2
LED175 DO | P$1 GND | P$3 DI P$4 | VDD P$2
LED176 DO | P$1 GND | P$3 DI P$4 | VDD P$2
LED177 DO | P$1 GND | P$3 DI P$4 | VDD P$2
LED178 DO | P$1 GND | P$3 DI P$4 | VDD P$2
LED179 DO | P$1 GND | P$3 DI P$4 | VDD P$2
LED180 DO | P$1 GND | P$3 DI P$4 | VDD P$2
LED181 DO | P$1 GND | P$3 DI P$4 | VDD P$2
LED182 DO | P$1 GND | P$3 DI P$4 | VDD P$2
LED183 DO | P$1 GND | P$3 DI P$4 | VDD P$2
LED184 DO | P$1 GND | P$3 DI P$4 | VDD P$2
LED185 DO | P$1 GND | P$3 DI P$4 | VDD P$2
LED186 DO | P$1 GND | P$3 DI P$4 | VDD P$2
LED187 DO | P$1 GND | P$3 DI P$4 | VDD P$2
LED188 DO | P$1 GND | P$3 DI P$4 | VDD P$2
LED189 DO | P$1 GND | P$3 DI P$4 | VDD P$2
LED190 DO | P$1 GND | P$3 DI P$4 | VDD P$2
LED191 DO | P$1 GND | P$3 DI P$4 | VDD P$2
LED192 DO | P$1 GND | P$3 DI P$4 | VDD P$2

C17

C18

C19

C20

C21

C22 | C²³ | C²⁴ R⁴ DI2/5.2B | DO³/4.1A
UE0112 | 1 Matrix 2

A

B | B
C | C
D | D

E

A

E

07/10/2025 05:48 p. m. | 3 | 5 Title: UE0118-Neopixel Shield v9
SKU: Last date time: | REV: SHEET: | of File: | Sheet description: | Author: Alberto Villanueva THE INFORMATION CONTAINED IN THIS DRAWING IS THE SOLE PROPERTY OF UNIT ELECTRONICS. ANY REPRODUCTION IN PART OR WHOLE IS

WS2812B | WS2812B | WS2812B | WS2812B | WS2812B | WS2812B | WS2812B | WS2812B VCC
VCC | VCC | VCC | VCC | VCC | VCC | VCC
WS2812B | WS2812B | WS2812B | WS2812B | WS2812B | WS2812B | WS2812B | WS2812B VCC
VCC | VCC | VCC | VCC | VCC | VCC | VCC
GND | GND | GND | GND | GND | GND | GND | GND
WS2812B | WS2812B | WS2812B | WS2812B | WS2812B | WS2812B | WS2812B | WS2812B VCC
VCC | VCC | VCC | VCC | VCC | VCC | VCC
GND | GND | GND | GND | GND | GND | GND | GND
WS2812B | WS2812B | WS2812B | WS2812B | WS2812B | WS2812B | WS2812B | WS2812B VCC
VCC | VCC | VCC | VCC | VCC | VCC | VCC
GND | GND | GND | GND | GND | GND | GND | GND
WS2812B | WS2812B | WS2812B | WS2812B | WS2812B | WS2812B | WS2812B | WS2812B VCC
VCC | VCC | VCC | VCC | VCC | VCC | VCC
GND | GND | GND | GND | GND | GND | GND | GND
WS2812B | WS2812B | WS2812B | WS2812B | WS2812B | WS2812B | WS2812B | WS2812B VCC
VCC | VCC | VCC | VCC | VCC | VCC | VCC
GND | GND | GND | GND | GND | GND | GND | GND
WS2812B | WS2812B | WS2812B | WS2812B | WS2812B | WS2812B | WS2812B | WS2812B VCC
VCC | VCC | VCC | VCC | VCC | VCC | VCC
GND | GND | GND | GND | GND | GND | GND | GND
WS2812B | WS2812B | WS2812B | WS2812B | WS2812B | WS2812B | WS2812B | WS2812B VCC
VCC | VCC | VCC | VCC | VCC | VCC | VCC
GND | GND | GND | GND | GND | GND | GND | GND

1uF

### VCC

### GND

1uF

### VCC

### GND

1uF

### VCC

### GND

1uF

### VCC

### GND

1uF

### VCC

### GND

1uF

### VCC

GND | 1uF VCC | GND | 1uF VCC | GND | 200
LED193 DO | P$1 GND | P$3 DI P$4 | VDD P$2
LED194 DO | P$1 GND | P$3 DI P$4 | VDD P$2
LED195 DO | P$1 GND | P$3 DI P$4 | VDD P$2
LED196 DO | P$1 GND | P$3 DI P$4 | VDD P$2
LED197 DO | P$1 GND | P$3 DI P$4 | VDD P$2
LED198 DO | P$1 GND | P$3 DI P$4 | VDD P$2
LED199 DO | P$1 GND | P$3 DI P$4 | VDD P$2
LED200 DO | P$1 GND | P$3 DI P$4 | VDD P$2
LED201 DO | P$1 GND | P$3 DI P$4 | VDD P$2
LED202 DO | P$1 GND | P$3 DI P$4 | VDD P$2
LED203 DO | P$1 GND | P$3 DI P$4 | VDD P$2
LED204 DO | P$1 GND | P$3 DI P$4 | VDD P$2
LED205 DO | P$1 GND | P$3 DI P$4 | VDD P$2
LED206 DO | P$1 GND | P$3 DI P$4 | VDD P$2
LED207 DO | P$1 GND | P$3 DI P$4 | VDD P$2
LED208 DO | P$1 GND | P$3 DI P$4 | VDD P$2
LED209 DO | P$1 GND | P$3 DI P$4 | VDD P$2
LED210 DO | P$1 GND | P$3 DI P$4 | VDD P$2
LED211 DO | P$1 GND | P$3 DI P$4 | VDD P$2
LED212 DO | P$1 GND | P$3 DI P$4 | VDD P$2
LED213 DO | P$1 GND | P$3 DI P$4 | VDD P$2
LED214 DO | P$1 GND | P$3 DI P$4 | VDD P$2
LED215 DO | P$1 GND | P$3 DI P$4 | VDD P$2
LED216 DO | P$1 GND | P$3 DI P$4 | VDD P$2
LED217 DO | P$1 GND | P$3 DI P$4 | VDD P$2
LED218 DO | P$1 GND | P$3 DI P$4 | VDD P$2
LED219 DO | P$1 GND | P$3 DI P$4 | VDD P$2
LED220 DO | P$1 GND | P$3 DI P$4 | VDD P$2
LED221 DO | P$1 GND | P$3 DI P$4 | VDD P$2
LED222 DO | P$1 GND | P$3 DI P$4 | VDD P$2
LED223 DO | P$1 GND | P$3 DI P$4 | VDD P$2
LED224 DO | P$1 GND | P$3 DI P$4 | VDD P$2
LED225 DO | P$1 GND | P$3 DI P$4 | VDD P$2
LED226 DO | P$1 GND | P$3 DI P$4 | VDD P$2
LED227 DO | P$1 GND | P$3 DI P$4 | VDD P$2
LED228 DO | P$1 GND | P$3 DI P$4 | VDD P$2
LED229 DO | P$1 GND | P$3 DI P$4 | VDD P$2
LED230 DO | P$1 GND | P$3 DI P$4 | VDD P$2
LED231 DO | P$1 GND | P$3 DI P$4 | VDD P$2
LED232 DO | P$1 GND | P$3 DI P$4 | VDD P$2
LED233 DO | P$1 GND | P$3 DI P$4 | VDD P$2
LED234 DO | P$1 GND | P$3 DI P$4 | VDD P$2
LED235 DO | P$1 GND | P$3 DI P$4 | VDD P$2
LED236 DO | P$1 GND | P$3 DI P$4 | VDD P$2
LED237 DO | P$1 GND | P$3 DI P$4 | VDD P$2
LED238 DO | P$1 GND | P$3 DI P$4 | VDD P$2
LED239 DO | P$1 GND | P$3 DI P$4 | VDD P$2
LED240 DO | P$1 GND | P$3 DI P$4 | VDD P$2
LED241 DO | P$1 GND | P$3 DI P$4 | VDD P$2
LED242 DO | P$1 GND | P$3 DI P$4 | VDD P$2
LED243 DO | P$1 GND | P$3 DI P$4 | VDD P$2
LED244 DO | P$1 GND | P$3 DI P$4 | VDD P$2
LED245 DO | P$1 GND | P$3 DI P$4 | VDD P$2
LED246 DO | P$1 GND | P$3 DI P$4 | VDD P$2
LED247 DO | P$1 GND | P$3 DI P$4 | VDD P$2
LED248 DO | P$1 GND | P$3 DI P$4 | VDD P$2
LED249 DO | P$1 GND | P$3 DI P$4 | VDD P$2
LED250 DO | P$1 GND | P$3 DI P$4 | VDD P$2
LED251 DO | P$1 GND | P$3 DI P$4 | VDD P$2
LED252 DO | P$1 GND | P$3 DI P$4 | VDD P$2
LED253 DO | P$1 GND | P$3 DI P$4 | VDD P$2
LED254 DO | P$1 GND | P$3 DI P$4 | VDD P$2
LED255 DO | P$1 GND | P$3 DI P$4 | VDD P$2
LED256 DO | P$1 GND | P$3 DI P$4 | VDD P$2

C25

C26

C27

C28

C29

C30 | C³¹ | C³² | R⁷ DO³/3.8E | DO⁴/5.3B
UE0112 | 1 Matrix 2

A

B | B
C | C
D | D

E

A

E

07/10/2025 05:48 p. m. | 4 | 5 Title: UE0118-Neopixel Shield v9
SKU: Last date time: | REV: SHEET: | of File: | Sheet description: | Author: Alberto Villanueva THE INFORMATION CONTAINED IN THIS DRAWING IS THE SOLE PROPERTY OF UNIT ELECTRONICS. ANY REPRODUCTION IN PART OR WHOLE IS

A

A

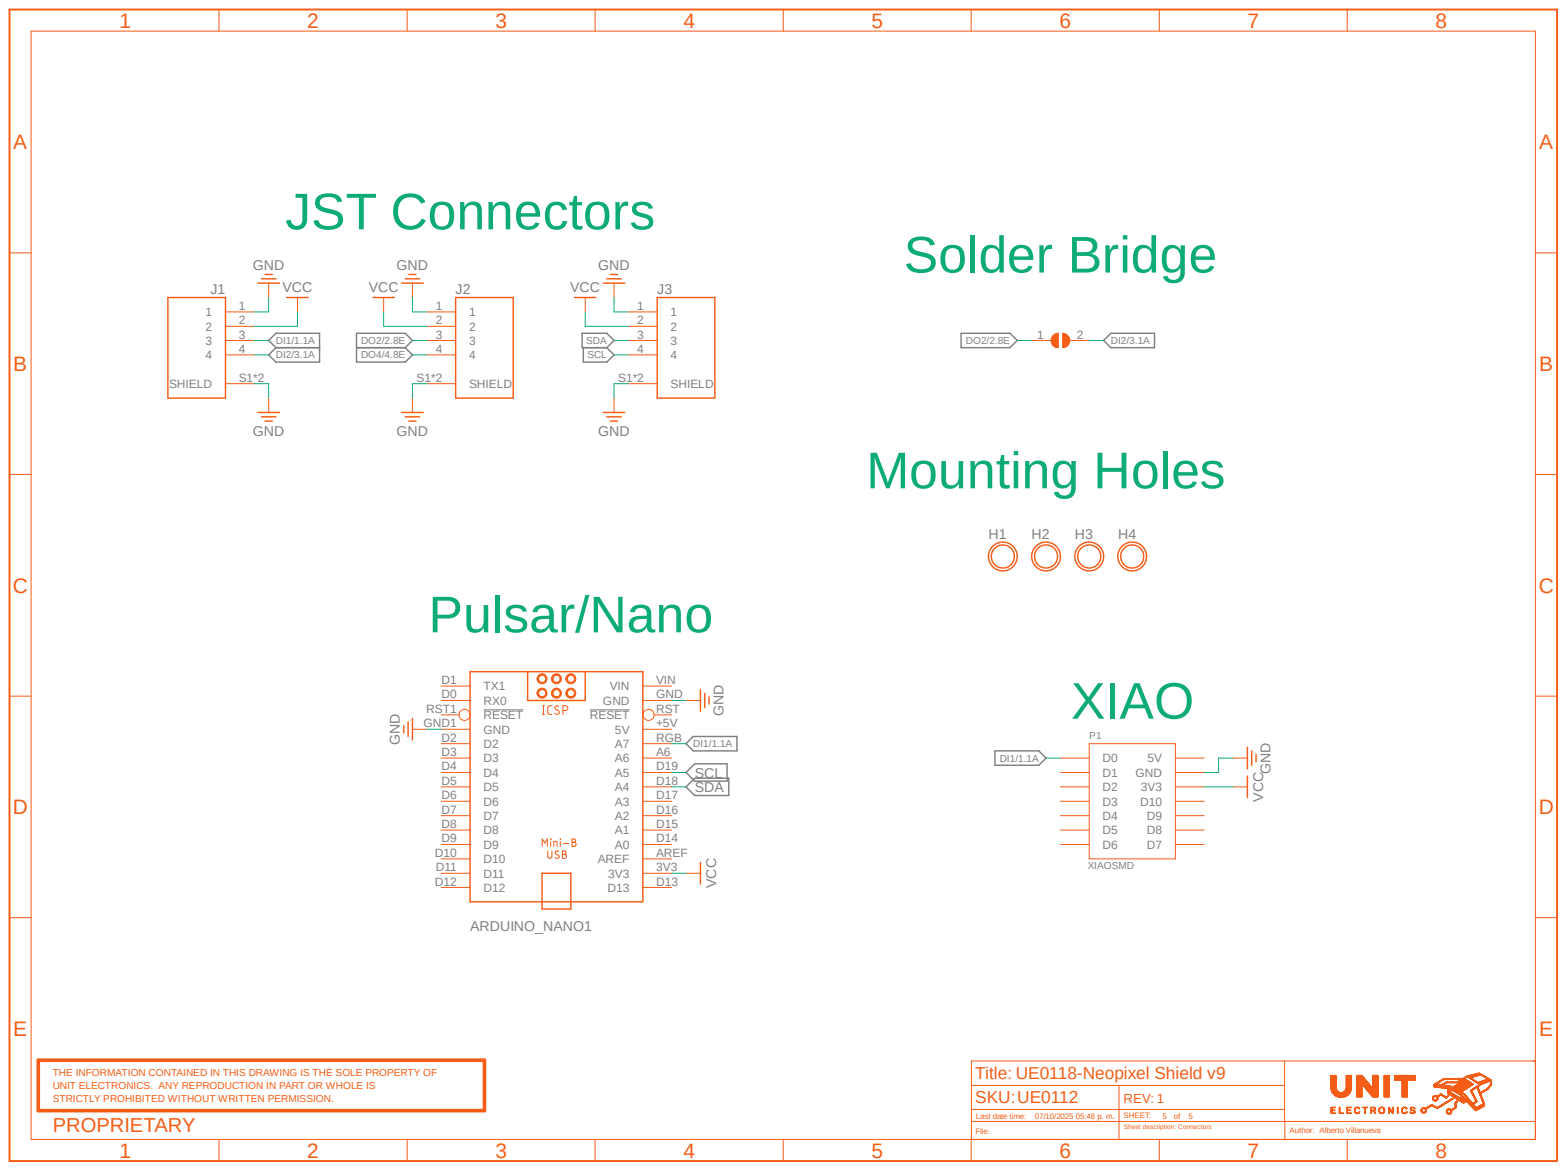
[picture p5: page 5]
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

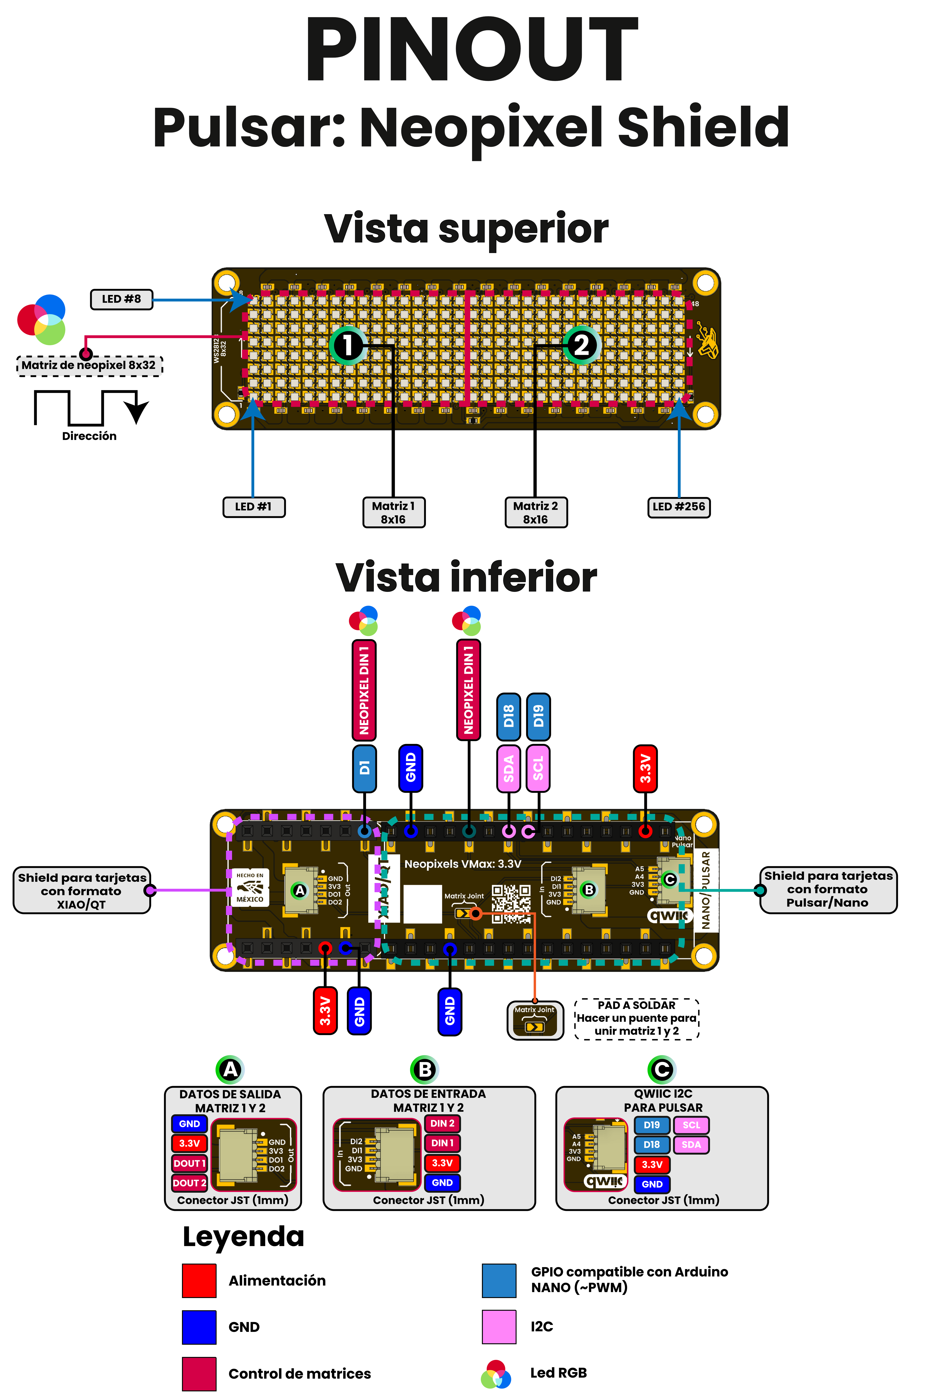
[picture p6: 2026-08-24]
docs/hardware/unit_pinout_v_1_0_0_ue00118_pulsar_neopixel_shield_en.png

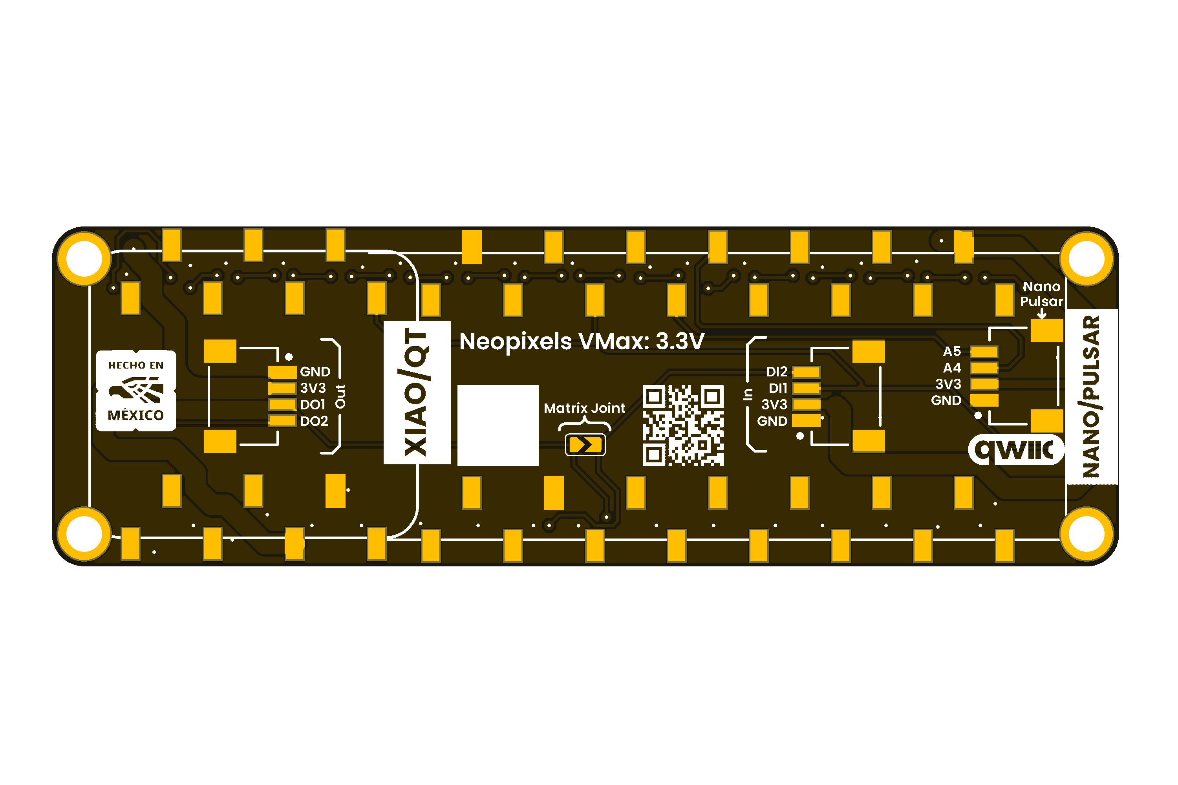
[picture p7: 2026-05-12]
docs/hardware/resources/unit_btm_v_1_0_0_pulsar_neopixel.jpg

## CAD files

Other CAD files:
docs/hardware/mechanics/unit_3d_ue0118_v_1_0_0_pulsar_ws2812b_shield.f3d

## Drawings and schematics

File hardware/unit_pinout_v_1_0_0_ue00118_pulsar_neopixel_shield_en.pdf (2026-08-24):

# PINOUT

# Pulsar: Neopixel Shield

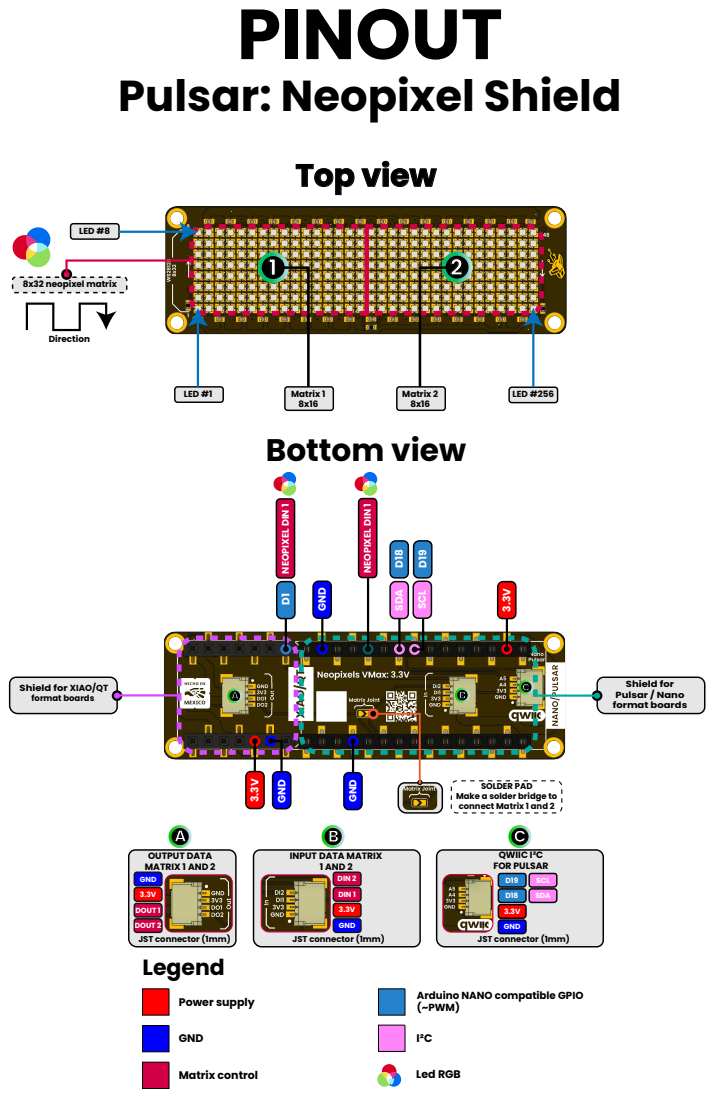
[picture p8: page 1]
Top view; Power supply; Arduino NANO compatible GPIO; (~PWM); GND; I²C; Matrix control; Led RGB; Legend; 8x32 neopixel matrix; Direction; LED #8; LED #1; Matrix 1; Matrix 2 8x16; LED #256; Bottom view; SDA; SCL; Shield for Pulsar / Nano format boards; NEOPIXEL DIN 1; GND 3.3V DOUT 1; DOUT 2; DIN 1; DIN 2; QWIIC I²C FOR PULSAR; OUTPUT DATA MATRIX 1 AND 2; INPUT DATA MATRIX 1 AND 2; JST connector (1mm)

GND NEOPIXEL DIN 1

Shield for XIAO/QT
format boards

SOLDER PAD
Make a solder bridge to
connect Matrix 1 and 2

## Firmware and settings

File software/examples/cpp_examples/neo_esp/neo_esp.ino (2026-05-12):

#include <Adafruit_NeoPixel.h>

#define PIN        8
#define NUM_LEDS   256  // 256 LEDs de matriz (sin offset)
#define MATRIX_WIDTH  8    // 8 columnas
#define MATRIX_HEIGHT 32   // 32 filas
#define DELAYVAL   100

// Control de brillo general (0-255)
// 255 = máximo brillo, 128 = 50% brillo, 64 = 25% brillo
#define BRILLO_GENERAL 128  // Cambia este valor para ajustar la luminosidad general

Adafruit_NeoPixel strip(NUM_LEDS, PIN, NEO_GRB + NEO_KHZ800);

// Función para escalar colores según el brillo general
uint32_t escalarColor(uint32_t color) {
  uint8_t r = (color >> 16) & 0xFF;
  uint8_t g = (color >> 8) & 0xFF;
  uint8_t b = color & 0xFF;
  
  // Escalar cada componente según BRILLO_GENERAL
  r = (r * BRILLO_GENERAL) / 255;
  g = (g * BRILLO_GENERAL) / 255;
  b = (b * BRILLO_GENERAL) / 255;
  
  return strip.Color(r, g, b);
}

// Función para convertir coordenadas x,y a índice LED
// Patrón ZIGZAG: filas pares van izq->der, filas impares van der->izq
int getPixelIndex(int x, int y) {
  if (x < 0 || x >= MATRIX_WIDTH || y < 0 || y >= MATRIX_HEIGHT) {
    return -1; // Fuera de los límites
  }
  
  // Patrón zigzag (serpentina):
  // Fila 0: 0->7 (izq a der)
  // Fila 1: 7->0 (der a izq)
  // Fila 2: 0->7 (izq a der)
  // etc...
  
  int index;
  if (y % 2 == 0) {
    // Fila par: izquierda a derecha
    index = y * MATRIX_WIDTH + x;
  } else {
    // Fila impar: derecha a izquierda (invertir X)
    index = y * MATRIX_WIDTH + (MATRIX_WIDTH - 1 - x);
  }
  
  return index; // Sin sumar +1 (sin offset)
}

// Definición de caracteres 5x8 ASCII completo (bit 1 = pixel encendido)
// Índices del 32 al 126 (caracteres imprimibles ASCII)
const uint8_t font5x8[][5] = {
  // 32: Espacio
  {0x00, 0x00, 0x00, 0x00, 0x00},
  // 33: !
  {0x00, 0x00, 0x5F, 0x00, 0x00},
  // 34: "
  {0x00, 0x07, 0x00, 0x07, 0x00},
  // 35: #
  {0x14, 0x7F, 0x14, 0x7F, 0x14},
  // 36: $
  {0x24, 0x2A, 0x7F, 0x2A, 0x12},
  // 37: %
  {0x23, 0x13, 0x08, 0x64, 0x62},
  // 38: &
  {0x36, 0x49, 0x55, 0x22, 0x50},
  // 39: '
  {0x00, 0x05, 0x03, 0x00, 0x00},
  // 40: (
  {0x00, 0x1C, 0x22, 0x41, 0x00},
  // 41: )
  {0x00, 0x41, 0x22, 0x1C, 0x00},
  // 42: *
  {0x14, 0x08, 0x3E, 0x08, 0x14},
  // 43: +
  {0x08, 0x08, 0x3E, 0x08, 0x08},
  // 44: ,
  {0x00, 0x50, 0x30, 0x00, 0x00},
  // 45: -
  {0x08, 0x08, 0x08, 0x08, 0x08},
  // 46: .
  {0x00, 0x60, 0x60, 0x00, 0x00},
  // 47: /
  {0x20, 0x10, 0x08, 0x04, 0x02},
  // 48: 0
  {0x3E, 0x51, 0x49, 0x45, 0x3E},
  // 49: 1
  {0x00, 0x42, 0x7F, 0x40, 0x00},
  // 50: 2
  {0x42, 0x61, 0x51, 0x49, 0x46},
  // 51: 3
  {0x21, 0x41, 0x45, 0x4B, 0x31},
  // 52: 4
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
};

// Mapeo de caracteres ASCII a índices en el array font5x8
int getCharIndex(char c) {
  // Mapeo directo ASCII: caracteres del 32 al 90 (espacio a Z)
  if (c >= 32 && c <= 90) {
    return c - 32; // Índice directo basado en código ASCII
  }
  // Convertir minúsculas a mayúsculas
  else if (c >= 97 && c <= 122) { // a-z
    return (c - 97) + (65 - 32); // Mapear a A-Z
  }
  else {
    return 0; // Espacio por defecto para caracteres no soportados
  }
}

// ============== SPRITES DE PERSONAJES ==============
// Sprites 8x8 píxeles (1 bit por píxel, 1 = encendido, 0 = apagado)

// Pikachu mejorado (8x8 píxeles)
const uint8_t spritePikachu[8] = {
  0b00111100,  // Fila 0: Orejas
  0b01111110,  // Fila 1: Parte superior cabeza
  0b11111111,  // Fila 2: Cabeza con orejas
  0b11011011,  // Fila 3: Ojos
  0b11111111,  // Fila 4: Mejillas rojas
  0b01111110,  // Fila 5: Cuerpo
  0b00111100,  // Fila 6: Parte inferior
  0b01000010   // Fila 7: Pies
};

// Pokébola (8x8 píxeles)
const uint8_t spritePokebola[8] = {
  0b00111100,  // Fila 0
  0b01111110,  // Fila 1: Parte superior roja
  0b11111111,  // Fila 2
  0b11111111,  // Fila 3: Línea negra centro
  0b11111111,  // Fila 4: Botón blanco centro
  0b11111111,  // Fila 5: Parte inferior blanca
  0b01111110,  // Fila 6
  0b00111100   // Fila 7
};

// Mario mejorado (8x8 píxeles)
const uint8_t spriteMario[8] = {
  0b00111100,  // Fila 0
  0b01111110,  // Fila 1
  0b00111100,  // Fila 2
  0b01011010,  // Fila 3
  0b00111100,  // Fila 4
  0b01111110,  // Fila 5
  0b01011010,  // Fila 6
  0b01100110   // Fila 7
};

// Mario saltando mejorado (8x8 píxeles)
const uint8_t spriteMarioJump[8] = {
  0b00111100,  // Fila 0
  0b01111110,  // Fila 1
  0b11111111,  // Fila 2
  0b00111100,  // Fila 3
  0b01000010,  // Fila 4
  0b11000011,  // Fila 5
  0b01000010,  // Fila 6
  0b01000010   // Fila 7
};

// Pac-Man (8x8 píxeles)
const uint8_t spritePacman[8] = {
  0b00111100,  // Fila 0
  0b01111110,  // Fila 1
  0b11111110,  // Fila 2: Boca abierta
  0b11111100,  // Fila 3
  0b11111100,  // Fila 4
  0b11111110,  // Fila 5
  0b01111110,  // Fila 6
  0b00111100   // Fila 7
};

// Hongo de Mario (8x8 píxeles)
const uint8_t spriteHongo[8] = {
  0b00000000,  // Fila 0
  0b00111100,  // Fila 1: Parte superior
  0b01111110,  // Fila 2: Sombrero rojo
  0b11111111,  // Fila 3: Puntos blancos
  0b11111111,  // Fila 4
  0b01111110,  // Fila 5: Tallo blanco
  0b01111110,  // Fila 6
  0b00111100   // Fila 7
};

// Corazón (8x8 píxeles)
const uint8_t spriteCorazon[8] = {
  0b00000000,  // Fila 0
  0b01100110,  // Fila 1
  0b11111111,  // Fila 2
  0b11111111,  // Fila 3
  0b11111111,  // Fila 4
  0b01111110,  // Fila 5
  0b00111100,  // Fila 6
  0b00011000   // Fila 7
};

// Estrella (8x8 píxeles)
const uint8_t spriteEstrella[8] = {
  0b00011000,  // Fila 0: Punta superior
  0b00011000,  // Fila 1
  0b01111110,  // Fila 2: Brazos
  0b00111100,  // Fila 3: Centro
  0b01111110,  // Fila 4
  0b11111111,  // Fila 5: Parte ancha
  0b01111110,  // Fila 6
  0b00100100   // Fila 7: Puntas inferiores
};

// Fantasma Pac-Man (8x8 píxeles)
const uint8_t spriteFantasma[8] = {
  0b00111100,  // Fila 0: Parte superior
  0b01111110,  // Fila 1
  0b11111111,  // Fila 2: Ojos
  0b11111111,  // Fila 3
  0b11111111,  // Fila 4: Cuerpo
  0b11111111,  // Fila 5
  0b11111111,  // Fila 6: Dientes
  0b11011011   // Fila 7: Dientes
};

// Nota Musical (8x8 píxeles)
const uint8_t spriteNota[8] = {
  0b01100000,  // Fila 0: Cabeza nota
  0b01100000,  // Fila 1: Cabeza nota
  0b01100000,  // Fila 2: Cabeza nota
  0b01100000,  // Fila 3: Vástago
  0b11110000,  // Fila 4: Vástago doble
  0b11110000,  // Fila 5: Vástago doble
  0b01100000,  // Fila 6: Conexión
  0b00000000   // Fila 7
};

// ============== FUNCIONES DE DIBUJO ==============

// Función para dibujar un sprite genérico centrado
void drawSprite(const uint8_t sprite[], int startX, int startY, uint32_t color) {
  uint32_t scaledColor = escalarColor(color);
  
  for (int row = 0; row < 8; row++) {
    uint8_t rowData = sprite[row];
    
    for (int col = 0; col < 8; col++) {
      if (rowData & (1 << (7 - col))) {
        // Rotación 90° horario
        int x = startX + row;
        int y = startY + col;
        
        if (x >= 0 && x < MATRIX_WIDTH && y >= 0 && y < MATRIX_HEIGHT) {
          int pixelIndex = getPixelIndex(x, y);
          if (pixelIndex >= 0) {
            strip.setPixelColor(pixelIndex, scaledColor);
          }
        }
      }
    }
  }
}

// Función para dibujar Pokébola con colores
void drawPokebola(int startX, int startY) {
  for (int row = 0; row < 8; row++) {
    uint8_t rowData = spritePokebola[row];
    
    for (int col = 0; col < 8; col++) {
      if (rowData & (1 << (7 - col))) {
        // Rotación 90° horario
        int x = startX + row;
        int y = startY + col;
        
        if (x >= 0 && x < MATRIX_WIDTH && y >= 0 && y < MATRIX_HEIGHT) {
          int pixelIndex = getPixelIndex(x, y);
          if (pixelIndex >= 0) {
            // Colorear según sección de la pokébola
            if (row < 4) {
              // Parte superior: roja
              strip.setPixelColor(pixelIndex, escalarColor(strip.Color(255, 0, 0)));
            } else {
              // Parte inferior: blanca
              strip.setPixelColor(pixelIndex, escalarColor(strip.Color(255, 255, 255)));
            }
          }
        }
      }
    }
  }
}

// Función para dibujar Hongo con colores
void drawHongo(int startX, int startY) {
  for (int row = 0; row < 8; row++) {
    uint8_t rowData = spriteHongo[row];
    
    for (int col = 0; col < 8; col++) {
      if (rowData & (1 << (7 - col))) {
        // Rotación 90° horario
        int x = startX + row;
        int y = startY + col;
        
        if (x >= 0 && x < MATRIX_WIDTH && y >= 0 && y < MATRIX_HEIGHT) {
          int pixelIndex = getPixelIndex(x, y);
          if (pixelIndex >= 0) {
            // Colorear según sección del hongo
            if (col < 2) {
              // Sombrero superior: rojo
              strip.setPixelColor(pixelIndex, escalarColor(strip.Color(255, 0, 0)));
            }
            // Tallo blanco (columnas 5-7)
            else {
              strip.setPixelColor(pixelIndex, escalarColor(strip.Color(240, 230, 200)));
            }
          }
        }
      }
    }
  }
}

// Función para dibujar Mario sin rotación (vertical)
void drawMario(const uint8_t sprite[], int startX, int startY, uint32_t color) {
  uint32_t scaledColor = escalarColor(color);
  
  for (int row = 0; row < 8; row++) {
    uint8_t rowData = sprite[row];
    
    for (int col = 0; col < 8; col++) {
      if (rowData & (1 << (7 - col))) {
        // Igual que Pokébola: rotar 90° horario
        int x = startX + col;
        int y = startY + (7 - row);
        
        if (x >= 0 && x < MATRIX_WIDTH && y >= 0 && y < MATRIX_HEIGHT) {
          int pixelIndex = getPixelIndex(x, y);
          if (pixelIndex >= 0) {
            strip.setPixelColor(pixelIndex, scaledColor);
          }
        }
      }
    }
  }
}

// Función para dibujar Corazón rotado 90° adicional con color personalizado
void drawCorazon(int startX, int startY, uint32_t color) {
  uint32_t scaledColor = escalarColor(color);
  
  for (int row = 0; row < 8; row++) {
    uint8_t rowData = spriteCorazon[row];
    
    for (int col = 0; col < 8; col++) {
      if (rowData & (1 << (7 - col))) {
        // Rotación ajustada para orientación correcta (no de cabeza)
        int x = startX + row;
        int y = startY + col;
        
        if (x >= 0 && x < MATRIX_WIDTH && y >= 0 && y < MATRIX_HEIGHT) {
          int pixelIndex = getPixelIndex(x, y);
          if (pixelIndex >= 0) {
            strip.setPixelColor(pixelIndex, scaledColor);
          }
        }
      }
    }
  }
}

// ============== ANIMACIONES DE SPRITES ==============

// Mostrar sprite estático centrado
void mostrarSpriteEstatico(const uint8_t sprite[], uint32_t color, int duracion) {
  strip.clear();
  drawSprite(sprite, 0, 12, color); // Centrado verticalmente
  strip.show();
  delay(duracion);
}

// Galería de sprites estáticos
void galeriaSprites() {
  // Pikachu
  mostrarSpriteEstatico(spritePikachu, strip.Color(255, 255, 0), 2000);
  delay(200);
  
  // Pokébola con colores
  strip.clear();
  drawPokebola(0, 12);
  strip.show();
  delay(2000);
  delay(200);
  
  // Mario
  mostrarSpriteEstatico(spriteMario, strip.Color(255, 0, 0), 2000);
  delay(200);
  
  // Hongo con colores
  strip.clear();
  drawHongo(0, 12);
  strip.show();
  delay(2000);
  delay(200);
  
  // Pac-Man
  mostrarSpriteEstatico(spritePacman, strip.Color(255, 255, 0), 2000);
  delay(200);
  
  // Corazón
  mostrarSpriteEstatico(spriteCorazon, strip.Color(255, 20, 147), 2000);
  delay(200);
  
  // Estrella
  mostrarSpriteEstatico(spriteEstrella, strip.Color(255, 215, 0), 2000);
  delay(200);
}

// Animación de aparición gradual (fade in)
void apareceSprite(const uint8_t sprite[], uint32_t color) {
  for (int brillo = 0; brillo <= 10; brillo++) {
    strip.clear();
    
    // Ajustar temporalmente el brillo
    int brilloOriginal = BRILLO_GENERAL;
    
    for (int row = 0; row < 8; row++) {
      uint8_t rowData = sprite[row];
      
      for (int col = 0; col < 8; col++) {
        if (rowData & (1 << (7 - col))) {
          int x = 0 + row;
          int y = 12 + col;
          
          if (x >= 0 && x < MATRIX_WIDTH && y >= 0 && y < MATRIX_HEIGHT) {
            int pixelIndex = getPixelIndex(x, y);
            if (pixelIndex >= 0) {
              uint8_t r = ((color >> 16) & 0xFF) * brillo / 10;
              uint8_t g = ((color >> 8) & 0xFF) * brillo / 10;
              uint8_t b = (color & 0xFF) * brillo / 10;
              strip.setPixelColor(pixelIndex, escalarColor(strip.Color(r, g, b)));
            }
          }
        }
      }
    }
    
    strip.show();
    delay(100);
  }
  delay(1500);
}

// Secuencia de apariciones
void secuenciaApariciones() {
  apareceSprite(spritePikachu, strip.Color(255, 255, 0));
  strip.clear();
  strip.show();
  delay(300);
  
  apareceSprite(spriteMario, strip.Color(255, 0, 0));
  strip.clear();
  strip.show();
  delay(300);
  
  apareceSprite(spriteCorazon, strip.Color(255, 20, 147));
  strip.clear();
  strip.show();
  delay(300);
}

// Pikachu parpadeando (centrado horizontalmente)
void pikachuParpadeo(int cycles) {
  for (int i = 0; i < cycles; i++) {
    strip.clear();
    drawSprite(spritePikachu, 0, 12, strip.Color(255, 255, 0)); // Amarillo, centrado
    strip.show();
    delay(800);
    
    strip.clear();
    strip.show();
    delay(200);
  }
}

// Mario caminando horizontalmente (a lo largo de las 32 filas)
void marioCamina(int duration) {
  for (int pos = -8; pos < MATRIX_HEIGHT + 8; pos++) {
    strip.clear();
    
    // Alternar entre sprite normal y saltando para simular caminar
    int xPos = 0; // Posición X fija (columna 0)
    if ((pos / 2) % 2 == 0) {
      drawMario(spriteMario, xPos, pos, strip.Color(255, 0, 0)); // Rojo
    } else {
      drawMario(spriteMarioJump, xPos, pos, strip.Color(255, 0, 0)); // Rojo
    }
    
    strip.show();
    delay(duration);
  }
}

// Animación de corazones moviéndose horizontalmente
void corazonesSubiendo(int numCorazones) {
  for (int i = 0; i < numCorazones; i++) {
    int offsetX = random(0, MATRIX_WIDTH - 8); // Posición X aleatoria
    
    for (int y = -8; y < MATRIX_HEIGHT + 8; y += 2) {
      strip.clear();
      drawCorazon(offsetX, y, strip.Color(255, 20, 147)); // Rosa/Magenta
      strip.show();
      delay(80);
    }
    delay(100);
  }
}

// Múltiples corazones moviéndose simultáneamente con diferentes colores
void corazonesSimultaneos(int numCorazones, int duracion) {
  int offsetsX[numCorazones];
  int posicionesY[numCorazones];
  uint32_t colores[numCorazones];
  
  // Colores variados para los corazones
  uint32_t paletaColores[] = {
    strip.Color(255, 20, 147),  // Rosa/Magenta
    strip.Color(255, 0, 100),   // Rosa oscuro
    strip.Color(255, 100, 150), // Rosa claro
    strip.Color(255, 50, 200),  // Rosa-púrpura
    strip.Color(255, 0, 255),   // Magenta puro
    strip.Color(200, 0, 150)    // Magenta oscuro
  };
  
  // Inicializar posiciones aleatorias más separadas
  for (int i = 0; i < numCorazones; i++) {
    offsetsX[i] = random(0, MATRIX_WIDTH - 8);
    posicionesY[i] = -8 - (i * 15); // Más separados (15 píxeles entre cada uno)
    colores[i] = paletaColores[i % 6]; // Asignar color de la paleta
  }
  
  // Animar todos simultáneamente
  for (int frame = 0; frame < duracion; frame++) {
    strip.clear();
    
    for (int i = 0; i < numCorazones; i++) {
      drawCorazon(offsetsX[i], posicionesY[i], colores[i]);
      posicionesY[i] += 2;
      
      // Reiniciar cuando sale por abajo
      if (posicionesY[i] > MATRIX_HEIGHT + 8) {
        posicionesY[i] = -8;
        offsetsX[i] = random(0, MATRIX_WIDTH - 8);
        colores[i] = paletaColores[random(0, 6)]; // Nuevo color aleatorio
      }
    }
    
    strip.show();
    delay(80);
  }
}

// Efecto de lluvia con colores arcoíris
void lluviaArcoiris(int duracion) {
  for (int frame = 0; frame < duracion; frame++) {
    // Agregar nuevas gotas aleatorias en la parte superior
    for (int i = 0; i < 3; i++) {
      int x = random(0, MATRIX_WIDTH);
      int hue = random(0, 65536);
      uint32_t color = escalarColor(strip.gamma32(strip.ColorHSV(hue)));
      int pixelIndex = getPixelIndex(x, 0);
      if (pixelIndex >= 0) {
        strip.setPixelColor(pixelIndex, color);
      }
    }
    
    // Mover todas las gotas hacia abajo
    for (int y = MATRIX_HEIGHT - 1; y > 0; y--) {
      for (int x = 0; x < MATRIX_WIDTH; x++) {
        int currentIndex = getPixelIndex(x, y);
        int aboveIndex = getPixelIndex(x, y - 1);
        if (currentIndex >= 0 && aboveIndex >= 0) {
          uint32_t colorAbove = strip.getPixelColor(aboveIndex);
          strip.setPixelColor(currentIndex, colorAbove);
        }
      }
    }
    
    strip.show();
    delay(80);
  }
}

// Efecto de estrellas parpadeando
void estrellasAleatorias(int duracion) {
  for (int frame = 0; frame < duracion; frame++) {
    strip.clear();
    
    // Dibujar estrellas aleatorias
    int numEstrellas = random(8, 15);
    for (int i = 0; i < numEstrellas; i++) {
      int x = random(0, MATRIX_WIDTH);
      int y = random(0, MATRIX_HEIGHT);
      int hue = random(0, 65536);
      uint32_t color = escalarColor(strip.gamma32(strip.ColorHSV(hue)));
      int pixelIndex = getPixelIndex(x, y);
      if (pixelIndex >= 0) {
        strip.setPixelColor(pixelIndex, color);
      }
    }
    
    strip.show();
    delay(100);
  }
}

// Onda de color que recorre la matriz
void ondaColor(int ciclos) {
  for (int ciclo = 0; ciclo < ciclos; ciclo++) {
    for (int offset = 0; offset < MATRIX_HEIGHT; offset++) {
      strip.clear();
      
      for (int y = 0; y < MATRIX_HEIGHT; y++) {
        for (int x = 0; x < MATRIX_WIDTH; x++) {
          int distancia = abs(y - offset);
          if (distancia < 4) {
            int brillo = 255 - (distancia * 64);
            int hue = (offset * 2000 + ciclo * 5000) % 65536;
            uint32_t color = escalarColor(strip.gamma32(strip.ColorHSV(hue, 255, brillo)));
            int pixelIndex = getPixelIndex(x, y);
            if (pixelIndex >= 0) {
              strip.setPixelColor(pixelIndex, color);
            }
          }
        }
      }
      
      strip.show();
      delay(50);
    }
  }
}

// Estrellas parpadeando en posiciones aleatorias
void estrellasParpadeo(int duration) {
  for (int i = 0; i < duration; i++) {
    strip.clear();
    
    // Dibujar varias estrellas en posiciones aleatorias
    int numEstrellas = random(2, 4);
    for (int e = 0; e < numEstrellas; e++) {
      int xPos = random(-4, MATRIX_WIDTH - 4);
      int yPos = random(0, MATRIX_HEIGHT - 8);
      drawSprite(spriteEstrella, xPos, yPos, strip.Color(255, 255, 0)); // Amarillo
    }
    
    strip.show();
    delay(300);
    
    strip.clear();
    strip.show();
    delay(200);
  }
}

// Fantasma flotando horizontalmente
void fantasmaFlotando(int cycles) {
  for (int cycle = 0; cycle < cycles; cycle++) {
    // Movimiento de izquierda a derecha
    int yPos = 12; // Centrado verticalmente
    
    for (int x = -8; x < MATRIX_WIDTH + 8; x++) {
      strip.clear();
      
      // Cambiar colores: azul, rosa, naranja, cyan
      uint32_t color;
      switch(cycle % 4) {
        case 0: color = strip.Color(0, 255, 255); break;   // Cyan
        case 1: color = strip.Color(255, 0, 255); break;   // Magenta
        case 2: color = strip.Color(255, 165, 0); break;   // Naranja
        case 3: color = strip.Color(255, 255, 255); break; // Blanco
      }
      
      drawSprite(spriteFantasma, x, yPos, color);
      strip.show();
      delay(60);
    }
  }
}

// Notas musicales moviéndose horizontalmente
void notasMusicales(int numNotas) {
  for (int i = 0; i < numNotas; i++) {
    int yPos = random(4, MATRIX_HEIGHT - 12); // Posición vertical aleatoria
    
    for (int x = -8; x < MATRIX_WIDTH + 8; x++) {
      strip.clear();
      
      // Colores variados para las notas
      uint32_t color;
      switch(i % 3) {
        case 0: color = strip.Color(255, 0, 255); break;   // Magenta
        case 1: color = strip.Color(0, 255, 255); break;   // Cyan
        case 2: color = strip.Color(255, 255, 0); break;   // Amarillo
      }
      
      drawSprite(spriteNota, x, yPos, color);
      strip.show();
      delay(50);
    }
    delay(50);
  }
}
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
void loop() {
  // === ANIMACIONES SELECCIONADAS ===
  
  // 1. Texto "UNIT" desplazándose con color blanco
  scrollText(reverseString("UNIT Electronics"), strip.Color(255, 255, 255), 100);
  delay(500);
  
  // 2. Tres Pokébolas moviéndose simultáneamente
  int pokebolaX[3];
  int pokebolaY[3];
  
  // Inicializar posiciones
  for (int i = 0; i < 3; i++) {
    pokebolaX[i] = random(0, MATRIX_WIDTH - 8);
    pokebolaY[i] = -8 - (i * 10); // Escalonadas
  }
  
  // Animar las 3 pokébolas al mismo tiempo
  bool todasTerminaron = false;
  while (!todasTerminaron) {
    strip.clear();
    todasTerminaron = true;
    
    for (int i = 0; i < 3; i++) {
      if (pokebolaY[i] < MATRIX_HEIGHT + 8) {
        drawPokebola(pokebolaX[i], pokebolaY[i]);
        pokebolaY[i] += 2;
        todasTerminaron = false;
      }
    }
    
    strip.show();
    delay(60);
  }
  
  delay(300);
  
  // 3. Corazones moviéndose simultáneamente (6 corazones durante 60 frames)
  corazonesSimultaneos(6, 60);
  delay(300);
  
  // 4. Lluvia arcoíris
  lluviaArcoiris(50);
  delay(300);
  
  // 5. Estrellas parpadeando
  estrellasAleatorias(30);
  delay(300);
  
  // 6. Onda de color
  ondaColor(2);
  delay(300);
  
  // 7. Texto arcoíris con corrección de orientación
  rainbowText(reverseString("MEXICO"), 80);
  delay(500);
}

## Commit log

2025-12-15 chore(docs): replace documentation scripts and update examples
    - Remove obsolete doc build scripts and workflow:
    - .github/scripts/build_docs.py
    - .github/scripts/config.sh
    - .github/scripts/deploy-to-pages.sh
    - .github/scripts/navbar-builder.sh
    - .github/scripts/smart-extract-docs.py
    - .github/workflows/deploy-mdbook.yml
    - software/examples/test/eeprom_test.ino
    - Add/replace shell-based scripts and new workflow:
    - .github/scripts/build_docs.sh
    - .github/scripts/clean_docs.sh
    - .github/scripts/copy_hardware_docs.py
    - .github/workflows/copy-hardware-docs.yml
    - Update examples documentation:
    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
    [neo_esp_offset.ino, neo_esp_test_serial.ino]
2026-05-12 Update Pulsar NeoPixel documentation and example structure
    * Update project README
    * Add Pulsar NeoPixel board images and schematic
    * Add new C++ example directory structure
    * Remove deprecated ICP10111 hardware resources
    * Remove legacy C and MicroPython examples
2026-06-04 docs(mechanics): Add 3D models
    [unit_3d_ue0118_v_1_0_0_pulsar_ws2812b_shield.f3d]
2026-06-04 Auto-update hardware documentation [skip ci]
    [unit_3d_ue0118_v_1_0_0_pulsar_ws2812b_shield.f3d]
2026-06-09 Update README.md
    Updated README to provide clearer structure and purpose for the software resources related to the RGB LED matrix shield project.
2026-06-09 Update README.md
    Expanded README to include detailed project structure and usage instructions for RGB LED matrix examples.
2026-06-09 Add LED matrix control example in README
    Added example code for controlling an 8x32 LED matrix using Adafruit NeoPixel library.
